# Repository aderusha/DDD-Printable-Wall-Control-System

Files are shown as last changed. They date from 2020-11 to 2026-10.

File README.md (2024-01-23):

# DDD Printable Wall Control System

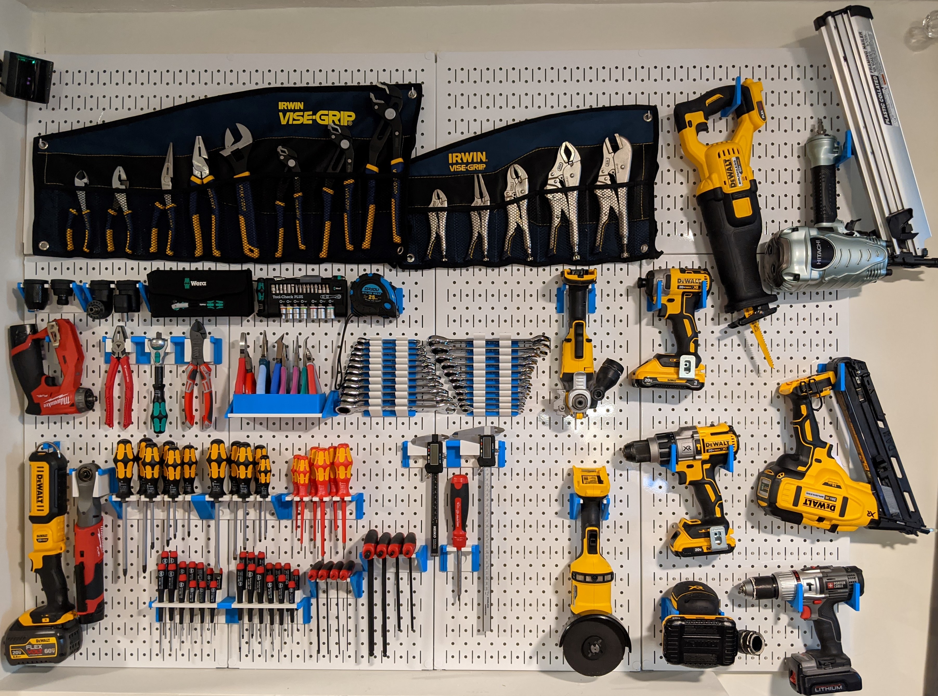
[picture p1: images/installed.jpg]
Installed DDD Printable Wall Control System


The DDD Printable Wall Control project provides a wide range of modular pegboard hangers for use with the [Wall Control powder-coated steel pegboard solutions available on Amazon](https://amzn.to/35emTsm).  After much research I landed on Wall Control as a durable, high-strength and low-price organization solution which works with existing 1/4" standard pegboard pegs.  The panels also add 1" slots which allows for greater strength and rigidity for compatible hangers.  I've found their panels to be inexpensive, well-made, and available in a range of colors and sizes.

Wall Control sells [a line of high quality hanger accessories compatible with these slots](https://amzn.to/35fkhuu) and I've found them to be reasonably priced and of good quality.  However, printed solutions can offer a highly-customized solutions made at home for your own organization needs and can do so quickly and inexpensively.  One might consider leveraging both solutions as needs arise.

---

## DDD Printable Wall Control Designs

The DDD Printable Wall Control collection is designed for easy printability, with all parts provided in a printable orientation and no supports should required.  The [Quickhooks](Quickhooks) series are fast-printing models for lightweight use cases.  [Sidepieces](Sidepieces) and [Centerpieces](Centerpieces) snap together to create strong, modular hanger solutions.

| [Quickhooks](Quickhooks) | |
| --- | --- |
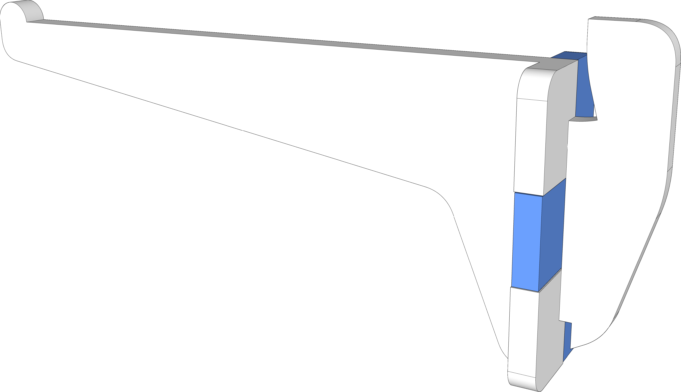
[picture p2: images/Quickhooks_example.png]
| [](Quickhooks) | [Quickhooks](Quickhooks) are fast-printing, two part hook/hanger solutions designed for quick and easy printing for lightweight use cases. Available in a range of sizes.|

| [Sidepieces](Sidepieces) | |
| --- | --- |
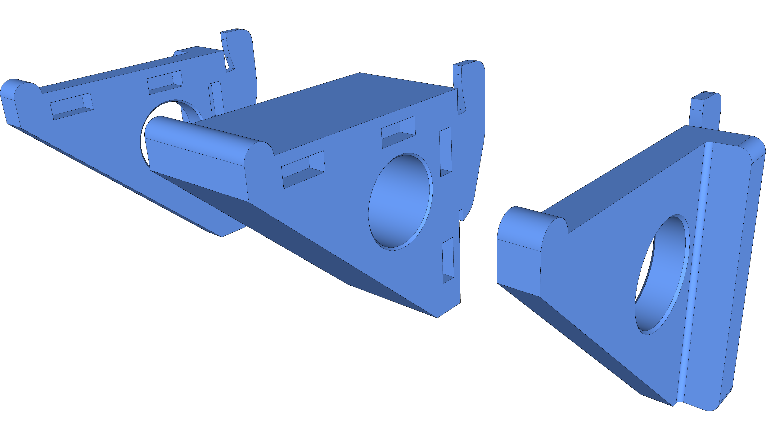
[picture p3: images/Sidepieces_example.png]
| [](Sidepieces) | [Sidepieces](Sidepieces) are designed with a hook that catches into the Wall Control slots.  Sidepieces extend out from the wall and come in a variety of lengths and shapes, and are offered in left/right/center variations.|

| [Centerpieces](Centerpieces) | |
| --- | --- |
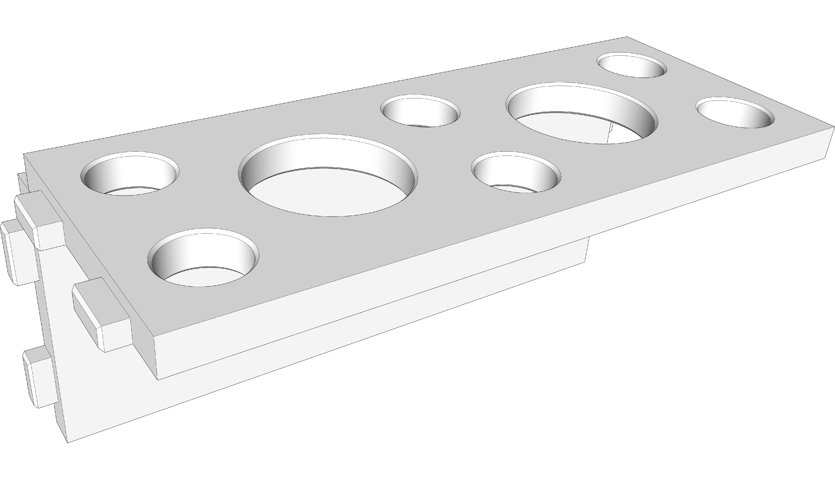
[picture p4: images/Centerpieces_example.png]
| [](Centerpieces) | [Centerpieces](Centerpieces) are designed to mount between a pair of sidepieces.  Centerpieces are designed to create custom hook, shelf, or hangar solutions which can snap into place between a variety of sidepieces. Some centerpiece models offer an additional locking feature which allows for completely rigid connections to a Wall Control panel.|

---

## Using DDD Printable Wall Control

The DDD system mixes "side pieces" with "center pieces"  to assemble a complete hanger.  Most use cases will involve a left/right combination of sidepieces with a centerpiece in the middle that will hold onto whatever you're hanging.

## Example DDD Printable Wall Control Recipe - belt clip hanger

Let's walk through an example hanger using DDD Printable Wall Control parts to create a hanger for tools with a belt clip such as a tape measure or pocket knife.  The completed model will look [something like this when empty](images/Recipies/belt-clip-hanger-empty.jpg) and [like this with some tools hung](images/Recipies/belt-clip-hanger-populated.jpg).

### Belt Clip Hanger printable BOM

Print the following parts for a 3in wide hanger as seen on the right in [the example photos above](images/Recipies/belt-clip-hanger-empty.jpg), substitute 4x wide or whatever you need for larger/smaller hangers.

* **1x [3x0 Flat Left.stl](Sidepieces/Flats/3x0%20Flat%20Left.stl)**  Left-hand sidepiece, 3 inches tall and flat in the front so there's nothing sticking forward. A sidepiece 3 high and 0 forward will have a filename starting with 3x0.
* **1x [3x0 Flat Right.stl](Sidepieces/Flats/3x0%20Flat%20Right.stl)**  Right hand sidepiece, same as above.
* **1x [2x3 Spacer clip-on.stl](Centerpieces/Spacer_clip-on/2x3%20Spacer%20clip-on.stl)**  Center hook for the clip, this one is 2in high and 3in across.  A centerpiece 2 high and 3 across will have a filename starting with 2x3.
* **1x [1x3 Locking Spacer.stl](Centerpieces/Locking_spacer/1x3%20Locking%20Spacer.stl)** Allows the hanger to be locked to the wall control panel via a locking pin.
* **1x [8mm Lock Pin.stl](Accessories/8mm%20Lock%20Pin.stl)**  Screws into the locking spacer to press a pin into the 1/4" holes on your Wall Control panel, providing a fully-constrained fit on the wall. Drive into place with a quarter-inch square drive ratchet. This is the core feature of this system, so print a bunch!
* **4x [4x10x8mm Pin.stl](Accessories/4x10x8mm%20Pin.stl)**  Some centerpieces do not have tabs on the model to press into the sidepiece, such as the "Spacer clip-on" centerpieces used in this recipe.  This is always a result of avoiding "supports" in the print job.  Print out a set of these 4 pins, press-fit on either side of the "Spacer clip-on" part, then press into the left/right sidepieces along with the Locking Spacer.

### To recap

* Sidepiece dimensions are `height x depth`
* Centerpiece dimensions are `height x width`
* Sidepieces come in left/right pairs.  They have a hook that connects to Wall Control and are usually used to attach a centerpiece to the wall
* Centerpieces usually are there to actually hold whatever you are trying to hang
* Locking spacers can be used to fully constrain the part so nothing moves around

### Geting Started tl;dr

Start with the centerpieces, find something suitable for the thing you want to hang, then find a matching set of sidepieces using the dimensions from the centerpiece.

# [More Recipes](https://github.com/aderusha/DDD-Printable-Wall-Control-System/wiki/Recipes)

[Check here](https://github.com/aderusha/DDD-Printable-Wall-Control-System/wiki/Recipes) for some parts lists ready-to-go to get an idea of how you can use this system, or add your own recipe to share your ideas with others!

# Other stuff

## Press-fit Tolerance

The parts are designed with a press-fit, one can use a vice or clamps to force the parts together.  The final fit will be determined by the calibration of your printer, if anything is loose you can add a drop of CA glue to keep parts held tightly.

## Locking Wall Control parts

Several [Centerpiece](Centerpieces) models offer a locking feature based on a fantastic idea from [Seth Altobelli](https://www.thingiverse.com/seth_a/designs).  A [locking screw](Centerpieces/Locking_spacer/8mm%20Lock%20Pin.stl) can be printed and screwed into these models to provide a solid, positive-lock fit with the Wall Control system.  A locked part is fully constrained and will not move while hanging or removing a tool which greatly improves the experience over traditional pegboard offerings.

The locking screw uses a 1/4" square drive, same as one would use to drive a 1/4" drive socket.

## About horizontal Wall Control Panels

Wall control sells panels which are oriented vertically or horizontally, and the hole patterns between the two are different. Centerpieces and sidepieces which make use of the locking feature have separate models for horizontal panels to accomodate the difference in hole patterns.

## About powder coated Wall Control Panels

Wall control panels are available in a range of colors or as a simple unpainted, steel sheet.  The slots cut in the plain steel panels are slightly wider than those in the powder coated panels due to the thickness of the paint itself.  The catches in these models are designed to attach firmly to the powder coated panels, while unpainted panels might have a little more play due to the difference in thickness.  If your assembled part doesn't fit tight, try including one of the locking parts to ensure a secure fit.

## Sources

While several-dozen variants of Quickhooks, Centerpieces and other models are available to download as `.stl` files; you can download and modify the following sources to customise various parts for your needs.

- *[SketchUp Sources](Sources/SketchUp)* - The original sources used to create the base models found in this repository. _Requires SketchUp 2021 or later, with [special instructions for exporting](https://github.com/aderusha/DDD-Printable-Wall-Control-System/issues/3#issuecomment-754100336)_.
- *[FreeCAD Sources](Sources/FreeCAD)* - Reverse-engineered parametric models maintained by [Flynn](https://github.com/f1yn). Includes source files for Quickhooks and Centerpieces, with more on the way. _Requires FreeCAD 0.20 or later, but can also be easily converted to `.step`_

## Join the discussion!

Click the [Discussions](https://github.com/aderusha/DDD-Printable-Wall-Control-System/discussions) link above to ask questions, get help, suggest new ideas, or submit your own models!

## [Buy me a coffee](https://www.buymeacoffee.com/gW5rPpsKR)

Buy me a coffee (https://www.buymeacoffee.com/gW5rPpsKR)

This project is powered by coffee.  [I might get a little weird about it at times](https://github.com/aderusha/RoastLearner), but it's not much of a stretch to suggest that coffee both powers and consumes a fair portion of my mental energy.  [Hook me up if you think these models are cool](https://www.buymeacoffee.com/gW5rPpsKR).  Thanks!

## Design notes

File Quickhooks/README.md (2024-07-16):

# DDD Printable Wall Control Quickhooks

Quickhooks are fast-printing, two part hook/hangar solutions designed for quick and easy printing for lightweight use cases. Quickhooks come in 3 variations based on strength (light/medium/heavy) and length (1/2/3").

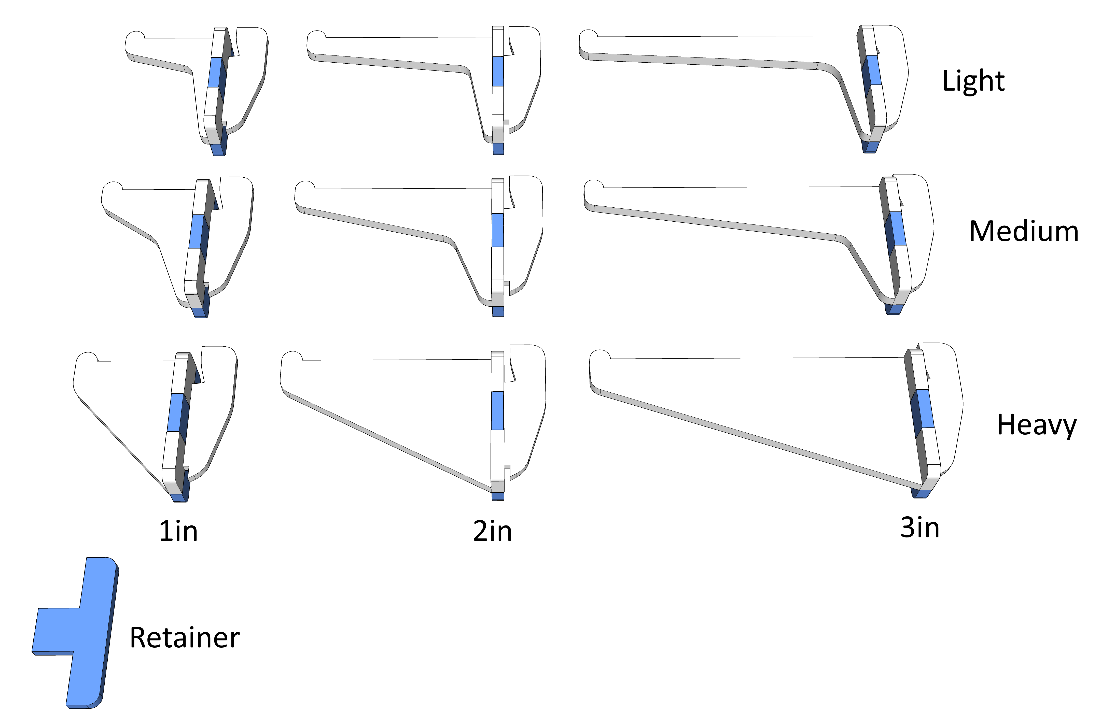
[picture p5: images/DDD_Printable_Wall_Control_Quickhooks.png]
Quickhooks


---

## Printing notes

Quickhooks should be suitable for fast printing, set your slicer up for maximum perimeters to ensure a strong printed result.  The retainer is press fit into the quickhook body. I use a clamp to apply a steady force to press the retainer into place. A rubber mallet is another good way to press fit together a quickhook and a retainer.

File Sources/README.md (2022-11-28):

# DDD Printable Wall Control System Source Designs

---

## Parametic templates in Fusion360 & STEP formats

These are for designing your own tool holders. 

| [Centerpiece Template](Fusion360/Parametric%20Centerpiece%20Template.f3d) | |
| --- | --- |
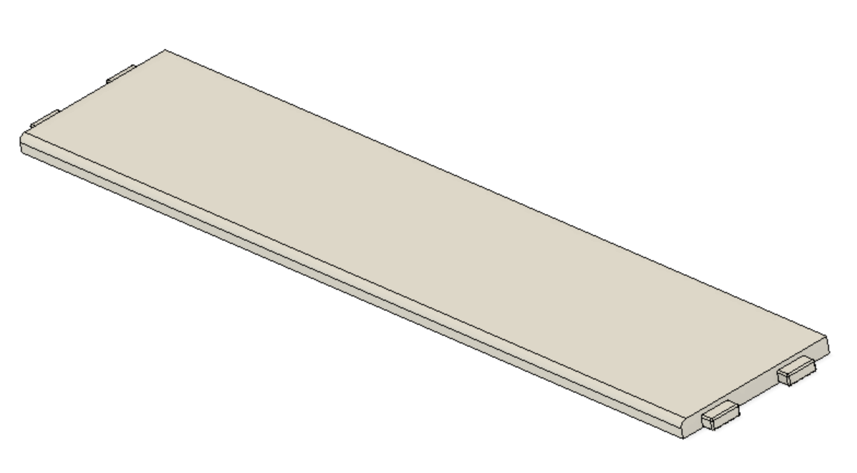
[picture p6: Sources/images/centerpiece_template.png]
| [](Fusion360/Parametric%20Centerpiece%20Template.f3d) | [Parametric Centerpiece Template](Fusion360/Parametric%20Centerpiece%20Template.f3d) is a simple centerpiece template for starting the design of your own tool holders. Specify parameters for the size and number of mounting tabs, then add your own sketches for custom fit holders. Also availabe in [STEP](Step/Parametric%20Centerpiece%20Template.f3d) format.|

| [Divider Rack Template](Fusion360/Parametric%20Centerpiece%20Divider%20Rack%20Template.f3d) | |
| --- | --- |
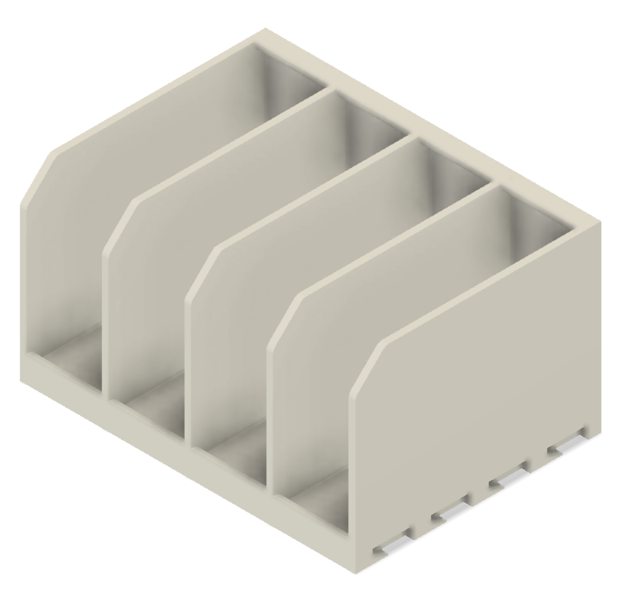
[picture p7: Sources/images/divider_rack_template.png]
| [](Fusion360/Parametric%20Centerpiece%20Divider%20Rack%20Template.f3d) | [Parametric Divider Rack Template](Fusion360/Parametric%20Centerpiece%20Divider%20Rack%20Template.f3d) is a simple centerpiece template for starting the design of storage for odd shaped items like pliers, brushes, phones, and more. Specify parameters for the size and number of mounting tabs, and the number of divded slots. Tall items (more than about 5 or 6cm) aren't able to be attached to [sidepieces](../Sidepieces/] first, and then attached to the wall control panel. They won't be able to lean back far enough for the mounting tabs to slot into the panel. So this template creates slots instead of tabs for the divider rack. Use the [4mmx10mmx8mm](../Accessories/4x10x8mm%20Pin.stl) pin provided in the [Accessories](../Accessories/), and press it into the sidepiece you choose. Then mount the sidepieces on the panel first, and you'll be able to attach the divider rack between them by lowering it onto the sidepiece tabs, and sliding it backwards to lock into place. The tolerances here are pretty generous so even if your printer isn't perfectly tuned, it should still fit. Also availabe in [STEP](Step/Parametric%20Centerpiece%20Divider%20Rack%20Template.step) format.|

---

## Using Parametric Source Files
These source files aren't directly printable and will need to be modified to suit your needs with some CAD tool that can use (or convert) F360 or Step formats. They use metric measurments. 

Save the template as a new file (to preserve the original template) and then modify as needed. You can specify the width (in "Units" on the Wall Control Board), Depth, and Height as well as the number of mounting tabs to use for attaching to [sidepieces](../Sidepieces/]. Then you can add your own sketches and extrusions to make holders for your own tools, and export that as a mesh to your slicer for printing. 

A "Width Unit" here is the meaurement between mounting slots, minus the mounting tabs. Vertical wall control panels have 14 units of width, and horizontal panels have 31. 

Available User Parameters

CenterPieceWidthUnits: Number of spaces on the wall control pegboard.  Minimum 1,  maximum 14 for vertical wall control panels and 31 for horizonal panels.  Realistically your printer dimensions will determin how big you can make this.

CenterPieceDepth: Depth measurement from the wall control board extending out into space.  Minimum 17mm to fit at least one mounting tab.  Maximum  ¯\\_(ツ)_/¯
CenterPieceThickness: Lower measurements make for good shelf-like objects,  taller measurement make for better custom tool holders.  Minimum 5mm to ensure there's enough space for mounting tabs. Maximum  ¯\\_(ツ)_/¯

CountMountingTabs: Specify the number of mounting tabs to attach a sidepiece

DividerWallThickness: Specify the thickness of the divider walls (including the outter side and back walls)

DividerWallHeight: Specify how tall the divider walls should be (including the outter side and back walls)

DividerSlots: Specify the number of tool storage slots.  Minimum 1 for a single compartment (one divider wall is always combined inside of a side wall).  Maximum  ¯\\_(ツ)_/¯

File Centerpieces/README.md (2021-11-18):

# DDD Printable Wall Control Centerpieces

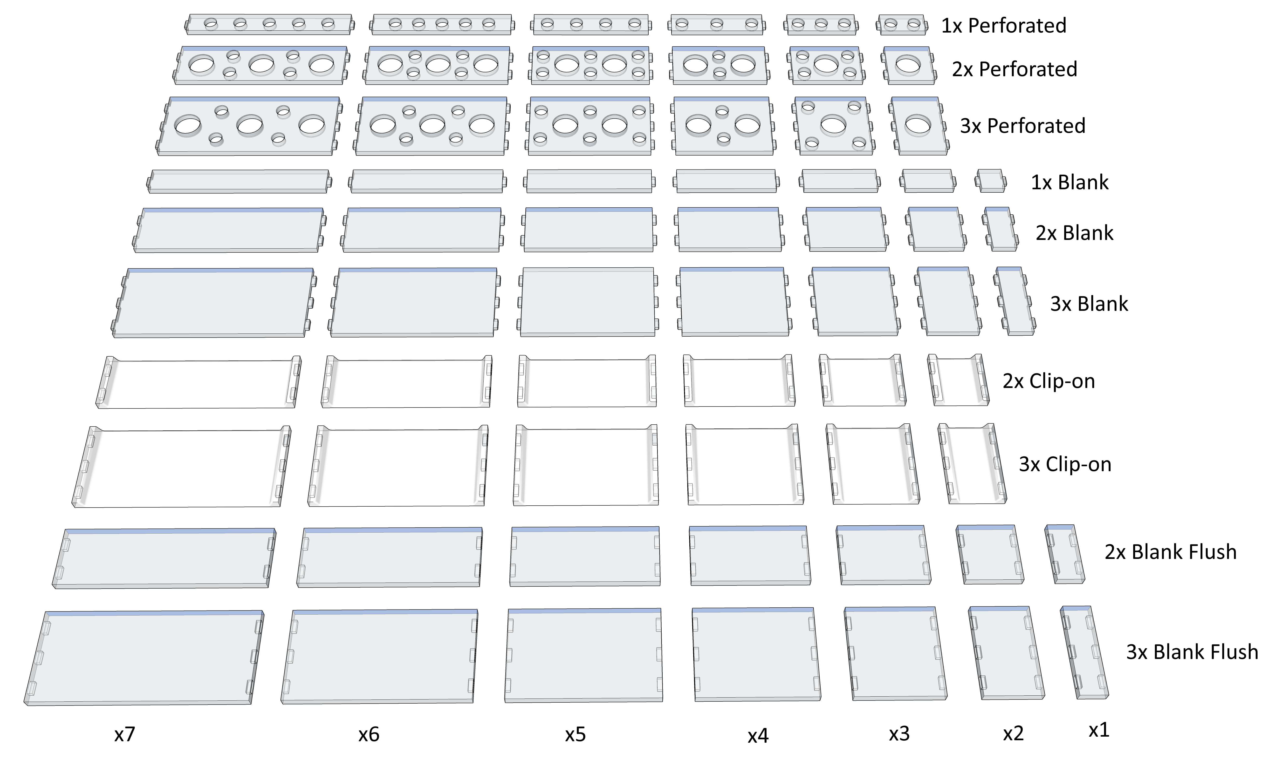
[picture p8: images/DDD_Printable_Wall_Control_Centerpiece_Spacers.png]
Centerpiece Spacers


Centerpieces mount between sidepieces to create a custom hanging solution by combining snap-fit modular components.

## Centerpiece Naming

Centerpiece names start with the dimensions, roughly equivalent to inches as used on the Wall Control system.  A 2x4 Centerpiece is 2in in height and fits between sidepieces that are 4in apart.

---

## Centerpiece Models

### [Tool_hooks](Tool_hooks/)

Centerpiece models designed for specific tools and applications.

### [Locking Spacer](Locking_spacer/)

Spacers with threads for the [8mm Lock Pin](Locking_spacer/8mm%20Lock%20Pin.stl) which will lock the assembled hanger to the Wall Control board.  Use these as vertical spacers between your sidepieces to create a solid mounting solution for nearly anything.

### [Locking Spacer for Horizontal Wall Control](Locking_spacer_for_horizontal_Wall_Control/)

Same as above, but for Horizontal Wall Control panels which have a different hole pattern.

### [Spacer Blank](Spacer_blank/)

Simple, blank models with connection pins on either side in various sizes.  Great choice for horizontal use as a shelf.

### [Spacer Blank Flush](Spacer_blank_flush/)

These spacers mount flush to both the back and front of the side pieces, which requires the use of 4 or 6 [4x10x8mm Pins](4x10x8mm Pin.stl) along the edges to connect them to a sidepiece. Another good choice for horizontal use as a shelf, I've also used these parts mounted vertically to provide a large flat surface for attaching adhesive-backed Velcro strips.

### [Clip-on Spacer](Spacer_clip-on/)

Another flush-mount design requiring 4 or 6 [4x10x8mm Pins](../Accessories/4x10x8mm%20Pin.stl) for mounting between side pieces.  The clip-on spacer provides a vertical surface set a few mm away from the wall panel so that one can mount clip-on parts such as a tape measure.

### [U hooks](U_hooks/)

U hooks useful for mounting horizontally between side pieces to hang tools.

### [Spacer Perforated](Spacer_perforated/)

Models with 1/2" and 1" holes along the flat surface for additional rigidity, interesting aesthetics, or to hold things with 1/2" or 1" round features.

---

## Printing notes

In most use cases, the centerpieces are loaded with a bending moment, which is only really a problem when using the longer (4"+) models.  Adding infill and perimeters can help with rigidity, but for most cases simply printing fast and cheap should work fine.  PLA is a good choice for maximum rigidity.

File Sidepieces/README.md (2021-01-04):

# DDD Printable Wall Control Sidepieces

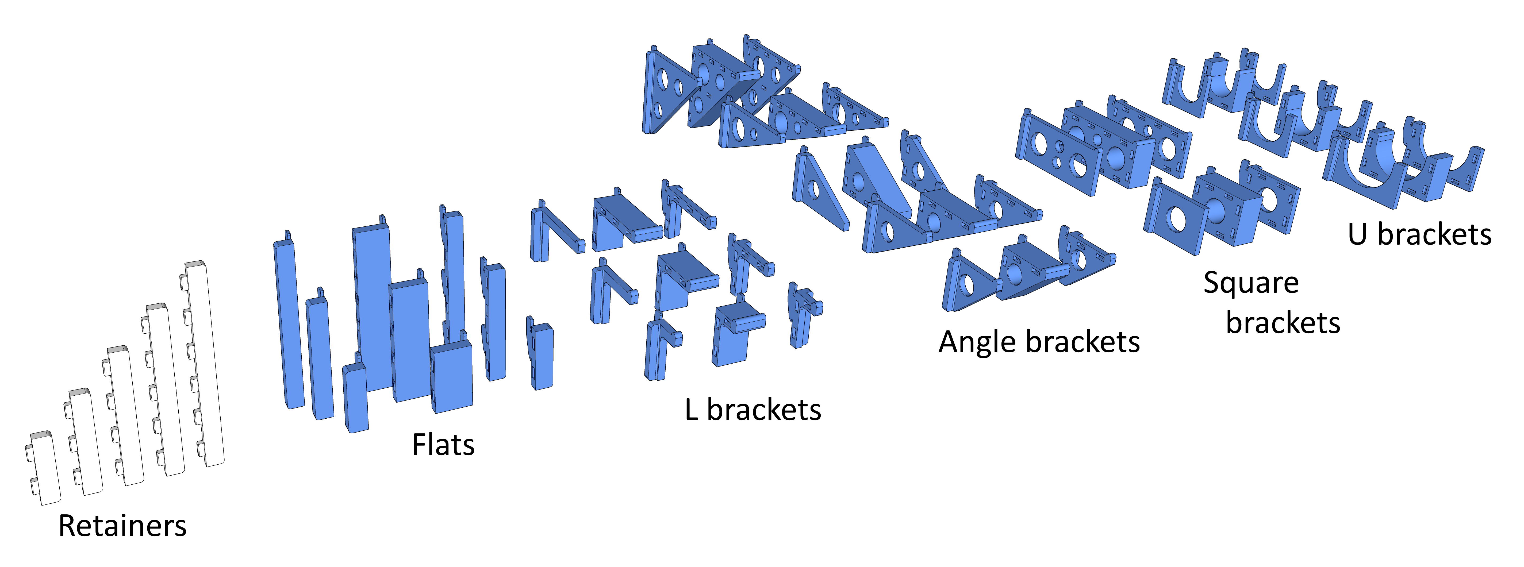
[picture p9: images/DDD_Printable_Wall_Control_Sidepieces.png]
Sidepieces


Sidepieces are used to connect to the Wall Control through the 1in slots and extend forward out from the wall.  Sidepieces can work on their own with a retainer which can be useful to create a single hook.  Alternately, sidepieces can be hooked together via centerpieces to create a wide range of modular hanging solutions.

## Sidepiece Naming

Sidepiece names start with the dimensions, roughly equivalent to inches as used on the Wall Control system.  For example, a 2x4 Sidepiece is 2in in height and extends 4in out from the base (which itself is 8.8mm in front of the wall panel).

---

## Sidepiece Models

### [Retainers](Retainers/)

Retainers are used when a sidepiece is used without one or more centerpieces, providing a secure fit against the Wall Control board.  Standard retainer models are narrow enough to allow side-by-side placement with an adjacent sidepiece + retainer.  Locking retainers are wider but can be used with the [8mm lock pin](Retainers/8mm%20Lock%20Pin.stl) to lock the hanger to the panel. Models are provided in 2/3/4/5/6 inch heights.

### [Flats](Flats/)

Simple, flat-surface sidepieces allowing centerpieces to be mounted vertically against the Wall Control board.  Useful with flush-mounted Centerpieces.

### [L Brackets](L_brackets)

"L" shaped brackets, good for lightweight loads or for use as hooks.  Models are available with a flat top, or with a 1/4" round "hook" feature which can help to retain parts hung on these models.

### [Angle Brackets](Angle_brackets)

Angle brackets good for holding moderate loads, general-purpose solution for mounting centerpieces horizontally.  Available in "flat" or "hook" variations.

### [Square Brackets](Square_brackets/)

Square brackets good for holding heavy loads.  With a full complement of centerpieces mounted between two square brackets, one can create a "torsion box" which can be helpful for mounting things which might be hanging off to one side of the hanger, presenting a twisting force on the bracket.  Available in "flat" or "hook" variations.

### [U Brackets](U_brackets/.)

U brackets are useful as "hooks" for mounting nearly anything.  Use with a [retainer](Retainers/) to create a single hook which is useful for hanging power tools, or combine a left/right pair of U brackets to hang a drill.

### [Dowel Rod Hangers](Dowel_rod_hanger/.)

Hangers to hold dowel rods, allowing one to mount things with a transverse hole such as spools.

---

## Printing notes

The sidepieces bear most of the load for an assembled hanger solution.  The downward forces press up against a catch on the bottom of the slot hook on each sidepiece, while the outward and rotational forces pull against the top-most portion of that same catch.  I've found printing with 100% perimeters in the catch area provides the strongest print. PLA is a good choice for maximum rigidity.

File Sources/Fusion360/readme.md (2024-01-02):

# Vertical Locking Spacers

[Note - submitted by @Akasnajo.  Thanks man!]

To create larger spacer panels:

To make taller, combine same-length panels as necessary... simply put the top/bottom faces together and combine into one body.

To make longer, identify two same-height panels that combine to yield the desired length.
Ignore (or delete) the tabs of the sides to be joined.
Place the two joining faces 2.4mm apart and extrude until they are joined.

If this is confusing, practice by combining two 1x2 pieces into a 2x2 panel and then combine two 2x1 panels into a 2x2 panel.
Compare to provided 2x2 panels to understand where adjustments must be made.

Thanks to those whose work this Fusion 360 version was created upon.

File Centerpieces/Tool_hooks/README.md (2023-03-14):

# DDD Printable Wall Control Centerpiece Tool Hooks

Centerpiece tool hooks designed for specific tool applications.

## Centerpiece Tool Hooks Naming

Centerpiece names start with the dimensions, roughly equivalent to inches as used on the Wall Control system.  A 2x4 Centerpiece is 2in in height and fits between sidepieces that are 4in apart.

---

## Centerpiece Tool Hooks

* ### 3x7 Benchtop Hand Tool [Tray](3x7%20Benchtop%20Hand%20Tool%20Holder%20Tray.stl) and [Holder](3x7%20Benchtop%20Hand%20Tool%20Holder.stl)

  Removable tray to hold 8 small hand tools like pliers or cutters.  Set your most commonly-used hand tools in the tray to give you an easy-to-grab solution to bring to your bench with all your tools in easy reach near the work.

* ### [11pc Wrench Hangers](1x6%2011pc%20Wrench%20Hanger.stl)

  Holds an 11 piece set of SAE box-end wrenches, combine with the [Inverted model](1x6%2011pc%20Wrench%20Hanger%20Inverted.stl) to hold a [22 piece set like this](https://amzn.to/35fa7dd).  Print with a left/right/center set of [6x0 Flats](../../Sidepieces/Flats) and at least 8x [4x10x8mm Pins](../Spacer_blank_flush/4x10x8mm%20Pin.stl).

* ### [2x4 10x](2x4%2010x%2010mm%20Screwdriver%20Holder.stl) and [2x5 13x 10mm Screwdriver Holder](2x5%2013x%2010mm%20Screwdriver%20Holder.stl)

  Holds 10x or 13x 10mm-wide screwdrivers (or similar).  I like [Wiha precision tools](https://amzn.to/2GQ8ucA) and these were designed to fit.  Combine with [2x2 L Brackets](../../Sidepieces/L_brackets/) and a [2x5 spacer](../../Centerpieces/Spacer_perforated/2x5%20Spacer%20perforated.stl).

* ### Chinese Digital Calipers [150mm](1x3%20Chinese%20Digital%20Calipers%20150mm.stl) and [300mm](1x3%20Chinese%20Digital%20Calipers%20300mm.stl)

  Designed for [150mm](https://amzn.to/3pcWByG) and [300mm](https://amzn.to/2UdfQdb) calipers of the sort you'll find from various Chinese vendors.  Combine with [2x1 L Brackets](../../Sidepieces/L_brackets/), a [2x3 locking spacer](../../Centerpieces/Locking_spacer/2x3%20Locking%20Spacer.stl), 4x [4x10x8mm Pins](../Spacer_blank_flush/4x10x8mm%20Pin.stl), and an [8mm Lock Pin](../../Centerpieces/Locking_spacer/8mm%20Lock%20Pin.stl) to keep it in place.

* ### Milwaukee M12 Battery holder for [one](2x2_milwaukee_M12_battery_x1.stl), [two](2x5_milwaukee_M12_battery_x2.stl), or [three](2x8_milwaukee_M12_battery_x3.stl) batteries

  Holders for M12 Milwaukee batteries. Each one requires [2x0 Flat Left](../../Sidepieces/Flats/2x0%20Flat%20Left.stl) and [2x0 Flat Right](../../Sidepieces/Flats/2x0%20Flat%20Right.stl) sidepieces along with 4 of the [4x10x8mm pins](../../Accessories/4x10x8mm%20Pin.stl). Photos available in my [Printables page](https://www.printables.com/model/352898-milwaukee-m12-battery-holder-for-wall-control-pegb). These were remixed from [Yangorang's design](https://www.printables.com/model/75300-power-tool-battery-wall-control-pegboard-mounts-fo) which requires nuts and bolts - whereas the version here is fully printable.
  
* ### Milwaukee M12 Generic Tool holders
  These are tool holders that should work for almost all Milwaukee M12 tools, although you should mind how heavy the tools are. There are several variations for holding the tools sideways and flat agains the pegboard (better for heavier tools) and angled ones where the tool points away from the wall:
    * [Straight](2x1_Milwaukee_M12_tool_holder_straight.stl): tool is held vertically and parallel to the wall, likelly better for some heavier tools since it won't stress the sidepiece hooks as much.
    * [Straight Extended](2x1_Milwaukee_M12_tool_holder_straight_extended.stl): Same as straight, but arm juts out further from pegboard for wider tools.
    * [Angled](2x1_Milwaukee_M12_tool_holder_angled.stl): 
  Each one requires [2x0 Flat Left](../../Sidepieces/Flats/2x0%20Flat%20Left.stl) and [2x0 Flat Right](../../Sidepieces/Flats/2x0%20Flat%20Right.stl) sidepieces along with 4 of the [4x10x8mm pins](../../Accessories/4x10x8mm%20Pin.stl). Photos available in my [Printables page](https://www.printables.com/model/352915-milwaukee-m12-tool-holders-for-wall-control-pegboa). These were remixed from [Yangorang's design](https://www.printables.com/model/75300-power-tool-battery-wall-control-pegboard-mounts-fo) which requires nuts and bolts - whereas the version here is fully printable. It also has added reinforcement on the arms.
  
  * ### [2.25x2 Milwaukee 3/8" Cordless Ratchet](2x2%20Milwaukee%203-8%20Cordless%20Ratchet.stl)

  Tool holder for the [Milwaukee 3/8" M12 Fuel Cordless Ratchet](https://amzn.to/2IsC9ZB).  Combine with a pair of [2x2 L Brackets](../../Sidepieces/L_brackets/).

* ### Wiha 33496 8-Piece T-Handle Hex Drivers ([M10/8/6/5](1x3%20Wiha%20T-Handle%20M10%20M8%20M6%20M5.stl) and [M4/3/2.5/2](1x4%20Wiha%20T-Handle%20M4%20M3%20M2.5%20M2.stl))

  Holders for the [Wiha 33496 8-Piece T-Handle Hex Driver set](https://amzn.to/36gpuRK), split into two parts.  The [larger set](1x3%20Wiha%20T-Handle%20M10%20M8%20M6%20M5.stl) needs to be set 3" away from the panel for the T-Handles to fit, so pair with [2x3 Angle Brackets](../../Sidepieces/Angle_brackets/) and a [2x4 spacer](../../Centerpieces/Spacer_perforated/2x4%20Spacer%20perforated.stl).  The [smaller set](1x4%20Wiha%20T-Handle%20M4%20M3%20M2.5%20M2.stl) can set closer to the wall if desired, using [2x2 Angle Brackets](../../Sidepieces/Angle_brackets/) and a [2x3 spacer](../../Centerpieces/Spacer_perforated/2x3%20Spacer%20perforated.stl).

* ### Wera 5023451001 10-Piece Imperial T-Handle Hex Plus Drivers ([Large drivers](2x5%20Wera%20HexPlus%20T-Handle%20Imperial%20Large.stl) and [Small drivers](2x4%20Wera%20HexPlus%20T-Handle%20Imperial%20Small.stl))

  Holders for the [Wera 5023451001 10-Piece Imperial T-Handle Hex Plus Drivers](https://amzn.to/3ggLkL6), split into two parts.  Pair with [2x2 Angle Brackets](../../Sidepieces/Angle_brackets/) and a [2x5 spacer](../../Centerpieces/Spacer_perforated/2x5%20Spacer%20perforated.stl) for the larger 5 drivers, and a [2x4 spacer](../../Centerpieces/Spacer_perforated/2x5%20Spacer%20perforated.stl) for the smaller 5 drivers

* ### [Wera 5023450001 7-Piece Metric T-Handle Hex Plus Drivers](2x6%20Wera%20HexPlus%20T-Handle%20Metric.stl)

  Holders for the [Wera 5023450001 7-Piece Metric T-Handle Hex Plus Drivers](https://amzn.to/3vfSXGa).  Pair with [2x3 Angle Brackets](../../Sidepieces/Angle_brackets/) and a [2x6 spacer](../../Centerpieces/Spacer_perforated/2x6%20Spacer%20perforated.stl)

* ### [Wera 5003550001 Zyklop 3/8" Ratchet](1x2%20Wera%203-8%20Zyklop%20Ratchet.stl)

  Fits the [Wera 5003550001 Zyklop 3/8" Ratchet](https://amzn.to/35fuVRI).  Combine with [1x2 L Brackets](../../Sidepieces/L_brackets/) and a [2x2 spacer](../../Centerpieces/Spacer_perforated/2x2%20Spacer%20perforated.stl).

* ### [Wera Kraftform Plus 160i/6 Insulated Screwdrivers](2x5%20Wera%20Kraftform%20Plus%20160i-6.stl)

  Fits the [Wera Kraftform Plus 160i/6 Insulated Screwdriver set](https://amzn.to/36il4tO).  Print with [2x2 Angle Brackets](../../Sidepieces/Angle_brackets/) and a [2x5 spacer](../../Centerpieces/Spacer_perforated/2x5%20Spacer%20perforated.stl).

* ### [Wera Kraftform 917+918 Chiseldrivers](2x6%20Wera%20917+918.stl)

  Holds a set of [6 drivers from the Wera 917 and 916 Chiseldrivers](https://amzn.to/35iAoXX) (1/2/3 Phillips and Pozidriv).  Print with [2x2 Angle Brackets](../../Sidepieces/Angle_brackets/) and a [2x6 spacer](../../Centerpieces/Spacer_perforated/2x5%20Spacer%20perforated.stl).  The 6" span on this needs some strength, I recommend printing this one with 100% perimeters.  It'll take a while to print but the result will be plenty rigid.

* ### [Wera Kraftform 923 slotted Chiseldrivers](2x5%20Wera%20932.stl)

  Holds a set of [5 Wera 932 slotted Chiseldrivers](https://amzn.to/35iAoXX).  Print with [2x2 Angle Brackets](../../Sidepieces/Angle_brackets/) and a [2x5 spacer](../../Centerpieces/Spacer_perforated/2x5%20Spacer%20perforated.stl).

* ### [NWS 138-69-200 Fantastico Plus Side Cutters](1x2%20NWS%20138-69-200%20Fantastico%20Plus%20Side%20Cutters.stl)

  Holds the fantastic [NWS 138-69-200 Fantastico Plus Side Cutters](https://amzn.to/3eNrbKv).  Combine with [1x2 L Brackets](../../Sidepieces/L_brackets/) and a [2x2 spacer](../../Centerpieces/Spacer_perforated/2x2%20Spacer%20perforated.stl).

* ### [Vampliers VT-001-8](1x2%20Vampliers%20VT-001-8.stl)

  Hanger for the best damn lineman's pliers ever made - the [Vampliers VT-001-8](https://amzn.to/3khDUpO).  Pair with [1x2 L Brackets](../../Sidepieces/L_brackets/) and a [2x2 spacer](../../Centerpieces/Spacer_perforated/2x2%20Spacer%20perforated.stl).

* ### [DeWalt DCB118 Charger](2x7%20DeWalt%20DCB118%20Charger.stl)

  Mount for the [DeWalt DCB118 20v/60v quick charger](https://amzn.to/36yhLio) with locking feature.  This is DeWalt's fastest charger yet, works with all modern 20v and 60v batteries.  Combine with [2x0 Flat Brackets](../../Sidepieces/Flats/), 4x [4x10x8mm Pins](../Spacer_blank_flush/4x10x8mm%20Pin.stl), and two [8mm Lock Pins](../../Centerpieces/Locking_spacer/8mm%20Lock%20Pin.stl) to keep it in place.

* ### [DeWalt DCB095 Charger](3x1%20DeWalt%20DCB095%20Charger.stl)

  Mount for the [DeWalt DCB095 8v charger](https://amzn.to/3fpajda) with locking feature.  Charger for the 8v battery system used by their [powered screwdrivers](https://amzn.to/3fpajda).  Print left/right [3x0 Flat Brackets](../../Sidepieces/Flats/), 4x [4x10x8mm Pins](../Spacer_blank_flush/4x10x8mm%20Pin.stl), and an [8mm Lock Pin](../../Centerpieces/Locking_spacer/8mm%20Lock%20Pin.stl) to keep it in place.

* ### [Milwaukee M12 Charger](4x3%20Milwaukee%20M12%20Charger.stl)

  Mount for the [Milwaukee M12 Charger](https://amzn.to/375AkL7) with locking feature, used for all M12 tools from Milwaukee.  Combine with [2x0 Flat Brackets](../../Sidepieces/Flats/), 4x [4x10x8mm Pins](../Spacer_blank_flush/4x10x8mm%20Pin.stl), and two [8mm Lock Pins](../../Centerpieces/Locking_spacer/8mm%20Lock%20Pin.stl) to keep it in place.

* ### [Milwaukee M12 FUEL Installation Drill/Driver](3x2%20Milwaukee%20M12%20Installation%20Drill.stl)

  Mount for the [Milwaukee M12 FUEL Installation Drill/Driver](https://amzn.to/3KmtOTe). Combine with Left/Right [3x0 Flat Brackets](../../Sidepieces/Flats/) to keep it in place. The [lock piece](3x2%20Milwaukee%20M12%20Installation%20Drill%20Lock.stl) is definitely optional. I thought I'd need it to keep it in place but it actually stays on the holder just fine without the lock piece.

* ### [28mm](2x2%2028mm%20Hammer%20Head%20Catch.stl) and [33mm Hammer Head Catch](2x2%2033mm%20Hammer%20Head%20Catch.stl)

  Mounts for claw/rip hammers, the 33mm was designed for the [Estwing Ultra Series 15oz E15SM](https://amzn.to/3puEnJa).  Pair with [2x2 L Brackets](../../Sidepieces/L_brackets/) and 4x [4x10x8mm Pins](../Spacer_blank_flush/4x10x8mm%20Pin.stl).

* ### [Porter Cable PCXMVC Charger](5x1%20Porter%20Cable%20PCXMVC%20Charger.stl)

  Mount for the Porter Cable PCXMVC Charger with locking feature, used for all 20V tools from Porter Cable.  Combine with left/right [5x0 Flat Brackets](../../Sidepieces/Flats/), 6x [4x10x8mm Pins](../Spacer_blank_flush/4x10x8mm%20Pin.stl), and two [8mm Lock Pins](../../Centerpieces/Locking_spacer/8mm%20Lock%20Pin.stl) to keep it in place.

---

## Printing notes

In most use cases, the centerpieces are loaded with a bending moment, which is only really a problem when using the longer (4"+) models.  Adding perimeters and infill can help with rigidity, but for most cases simply printing fast and cheap should work fine.  PLA is a good choice for maximum rigidity.

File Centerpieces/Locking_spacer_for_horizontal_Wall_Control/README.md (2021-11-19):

# DDD Printable Wall Control Locking Spacers for Horizontal Wall Control

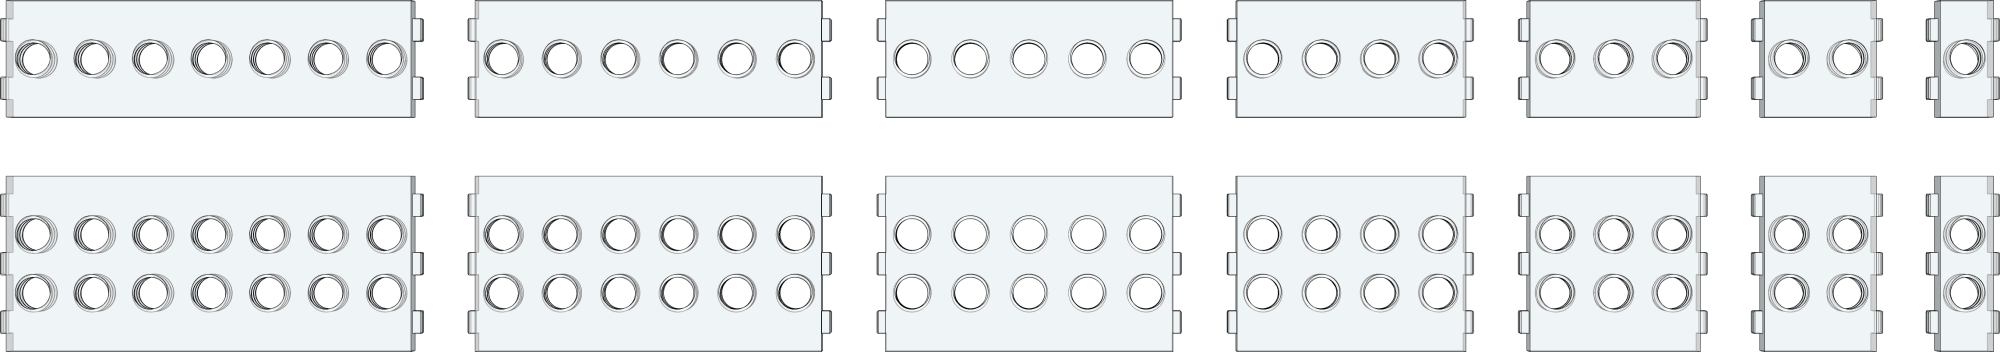
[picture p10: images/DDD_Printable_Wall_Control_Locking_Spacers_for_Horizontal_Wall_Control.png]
Locking Spacers


The locking spacer models provide an array of threaded holes which align with the 1/4" pegboard holes on a horizontal Wall Control panel.  Once mounted to the panel, you can screw in a [positive-lock pin](./8mm%20Lock%20Pin.stl) which securely anchors the model to a wall control panel in all 3 axis.  The pin has a cutout for a 1/4" square drive to screw it into the spacer.

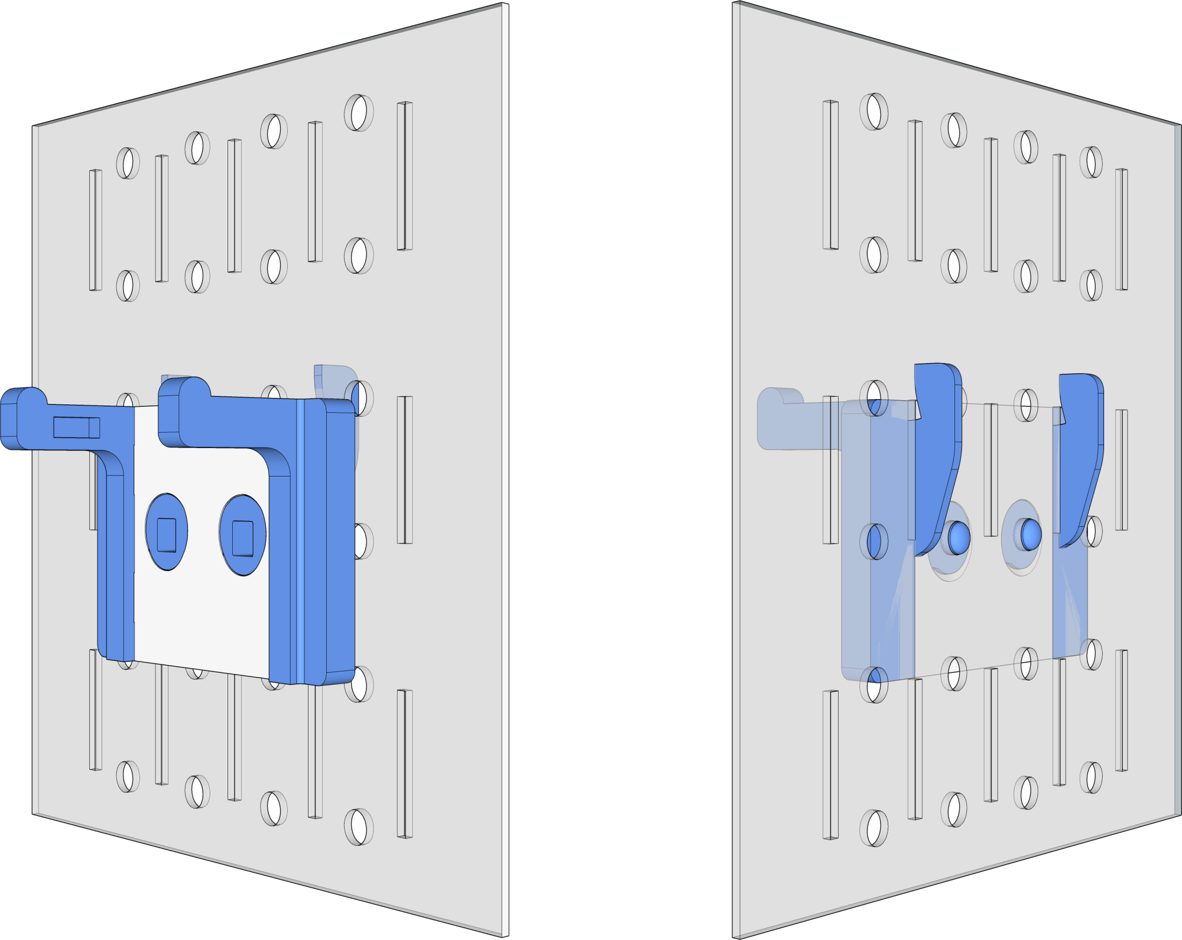
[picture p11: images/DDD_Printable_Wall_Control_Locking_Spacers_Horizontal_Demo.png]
Locking Spacer Demo


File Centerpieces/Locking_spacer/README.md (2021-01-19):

# DDD Printable Wall Control Locking Spacers

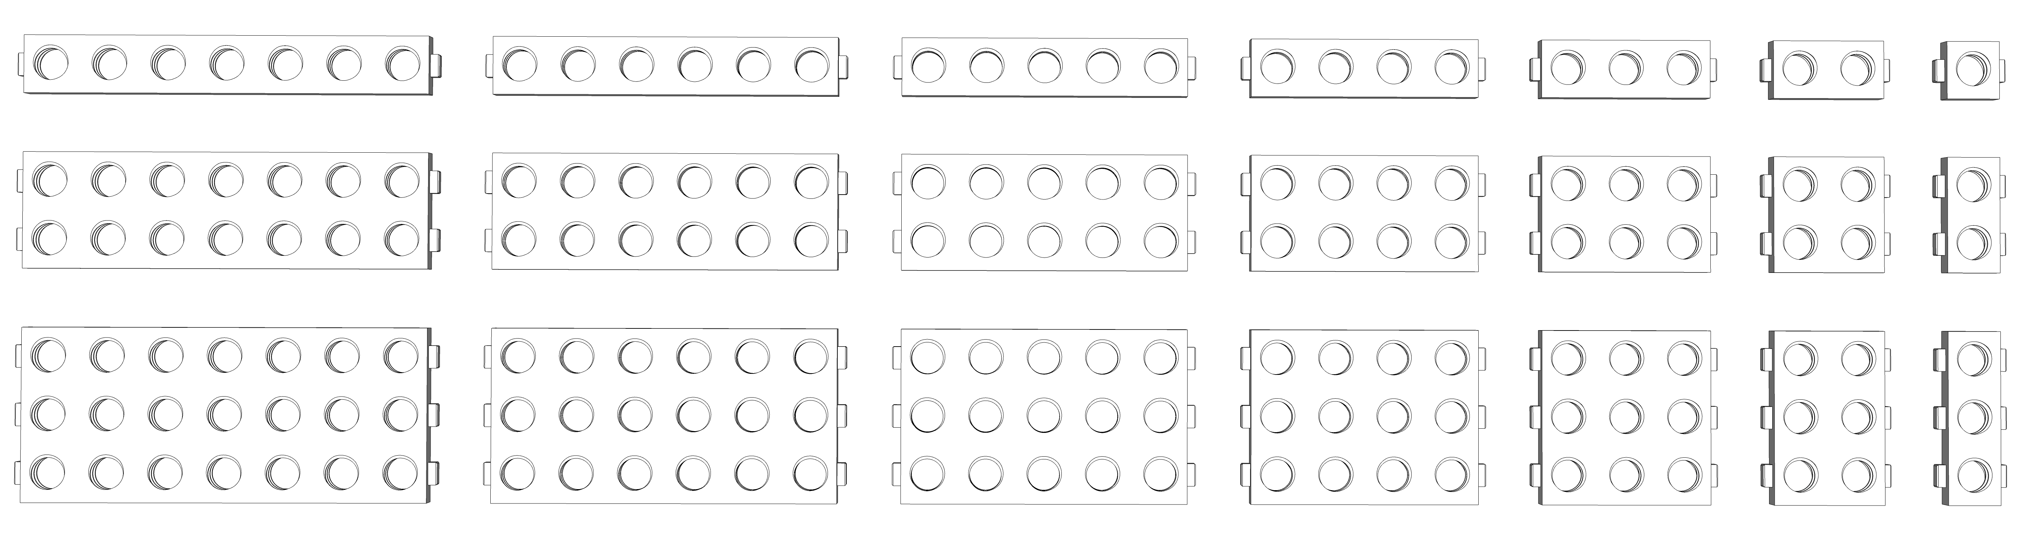
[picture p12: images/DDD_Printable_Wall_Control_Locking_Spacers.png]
Locking Spacers


The locking spacer models provide an array of threaded holes which align with the 1/4" pegboard holes on a Wall Control panel.  Once mounted to the panel, you can screw in a [positive-lock pin](./8mm%20Lock%20Pin.stl) which securely anchors the model to a wall control panel in all 3 axis.  The pin has a cutout for a 1/4" square drive to screw it into the spacer.

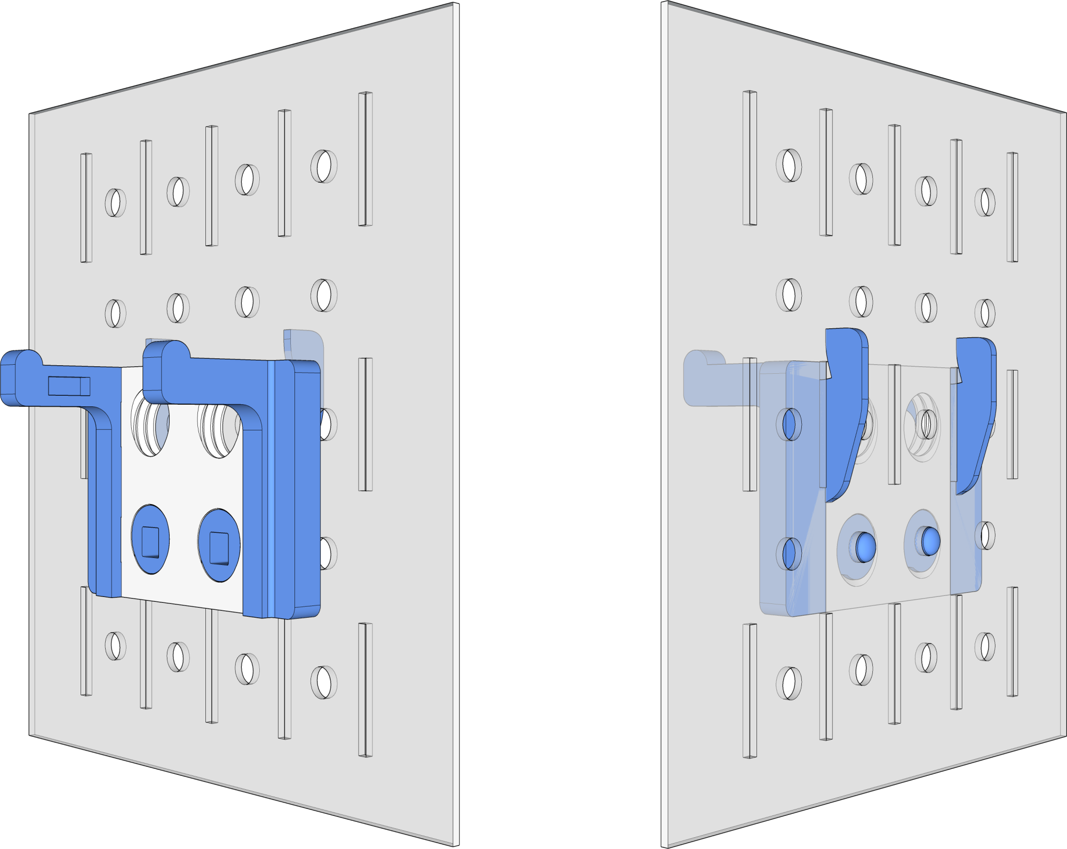
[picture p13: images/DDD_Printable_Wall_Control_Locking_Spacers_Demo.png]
Locking Spacer Demo


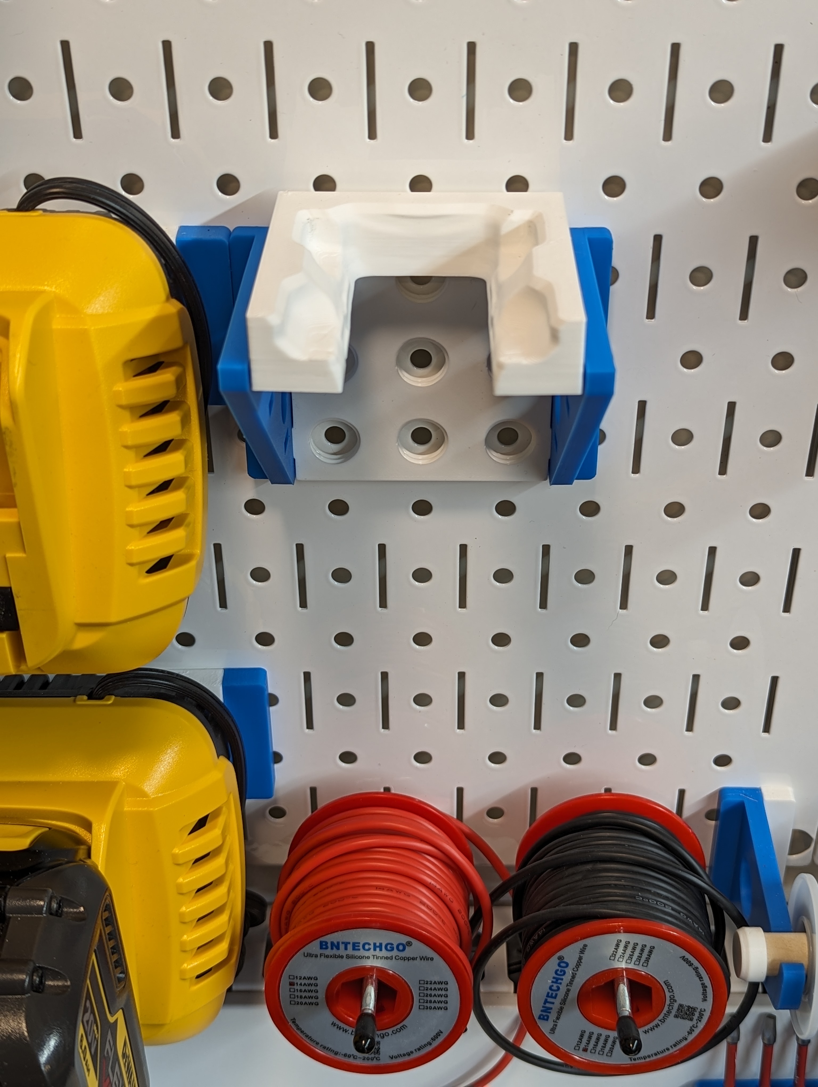
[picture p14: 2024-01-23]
images/Recipies/DeWalt-DCF923-empty.jpg

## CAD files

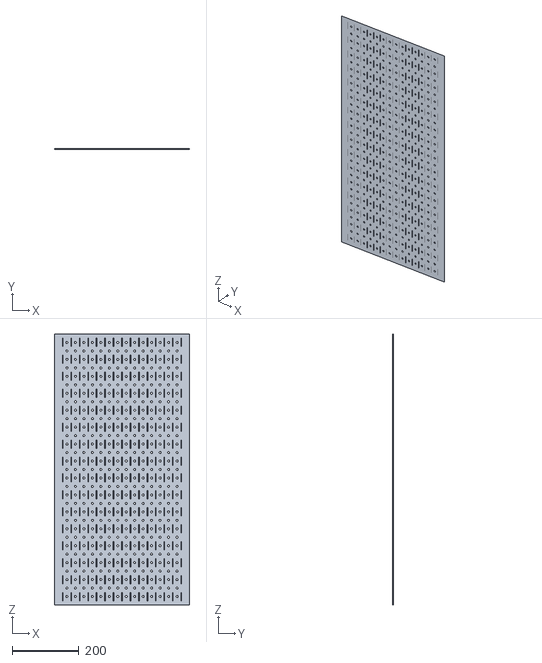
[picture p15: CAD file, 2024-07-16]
Accessories/Wall Control Panel Model.stl
406.4 x 1.59 x 812.8

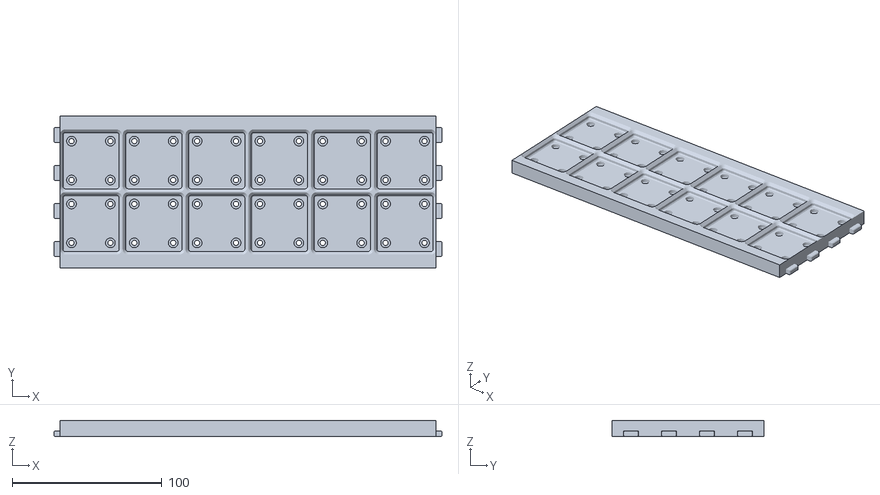
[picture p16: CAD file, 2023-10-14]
Centerpieces/Gridfinity/4x10 Gridfinity Frame 2x6.stl
259.4 x 101.4 x 10.8

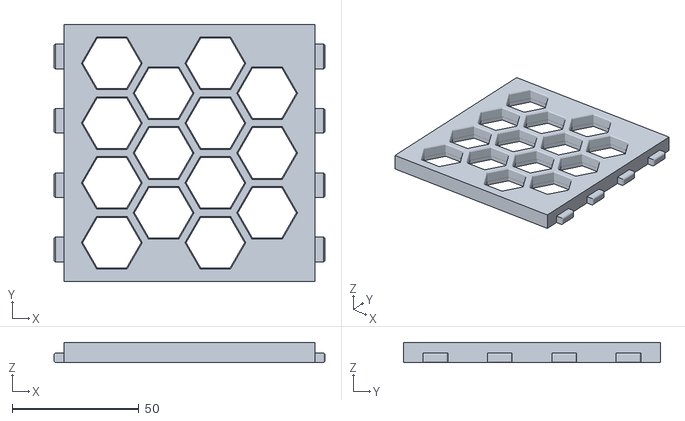
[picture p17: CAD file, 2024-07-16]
Centerpieces/Honeycomb_Storage_Wall/4x4 Honeycomb Storage Wall.stl
107.0 x 101.4 x 8.00

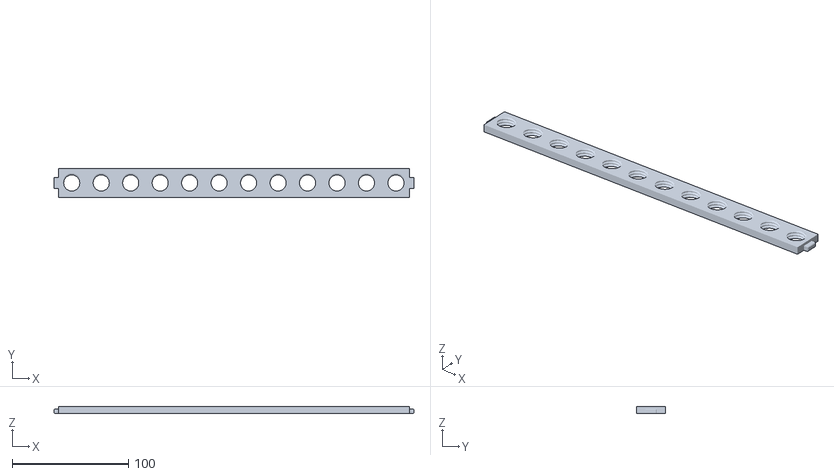
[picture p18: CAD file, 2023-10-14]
Centerpieces/Locking_spacer/1x12 Locking Spacer.stl
310.2 x 25.2 x 6.15

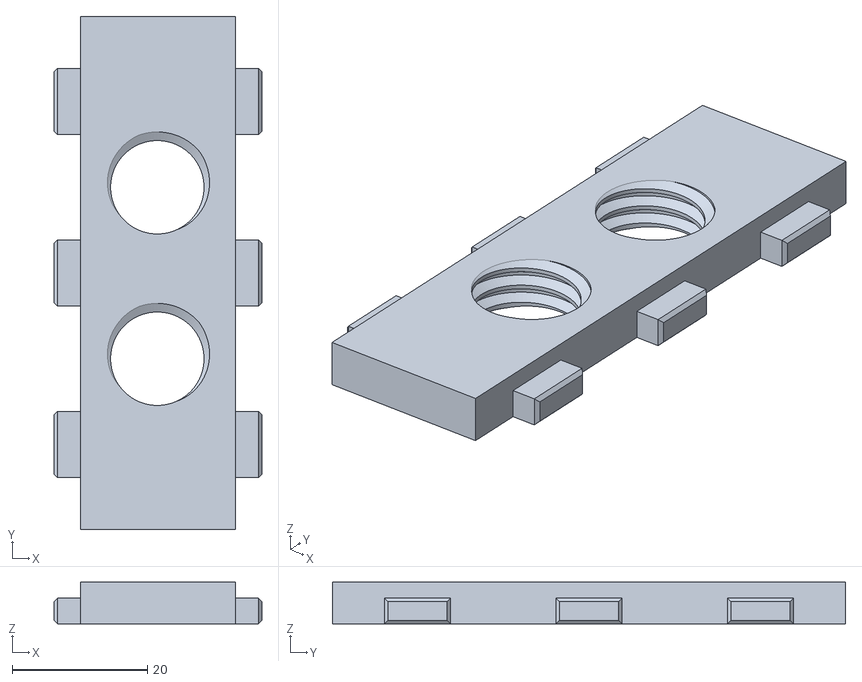
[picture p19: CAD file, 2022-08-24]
Centerpieces/Locking_spacer_for_horizontal_Wall_Control/3x1 Locking Spacer for horizontal Wall Control.stl
30.8 x 76.0 x 6.15

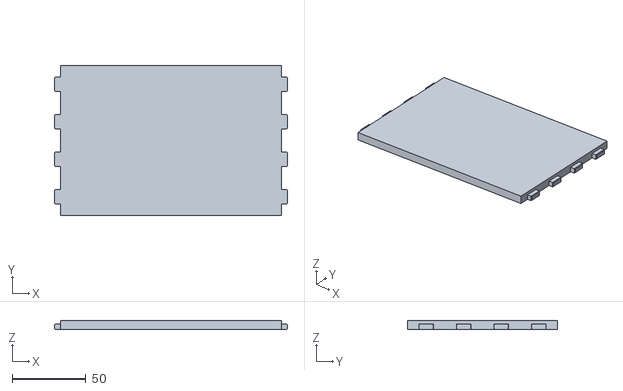
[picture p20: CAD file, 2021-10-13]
Centerpieces/Spacer_blank/4x6 Spacer blank.stl
157.8 x 101.4 x 6.15

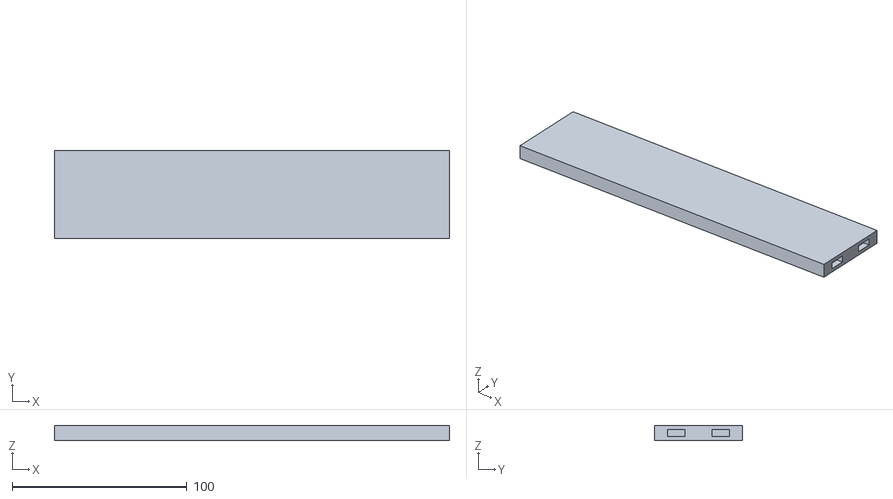
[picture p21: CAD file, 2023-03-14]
Centerpieces/Spacer_blank_flush/2x9 Spacer blank flush.stl
226.2 x 50.6 x 8.70

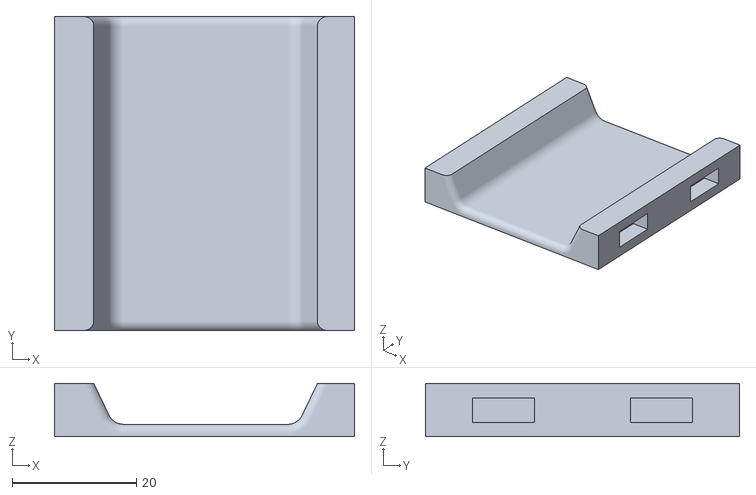
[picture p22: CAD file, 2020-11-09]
Centerpieces/Spacer_clip-on/2x2 Spacer clip-on.stl
48.4 x 50.6 x 8.60

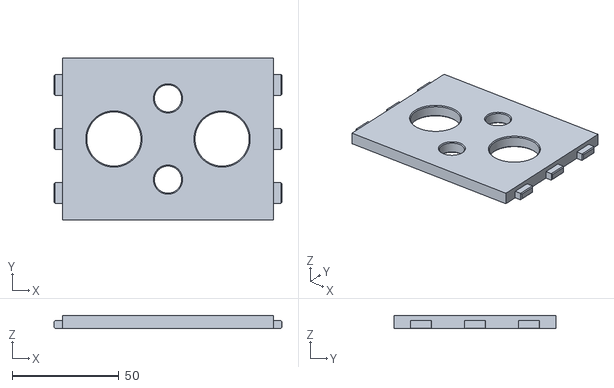
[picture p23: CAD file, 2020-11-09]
Centerpieces/Spacer_perforated/3x4 Spacer perforated.stl
107.0 x 76.0 x 6.15

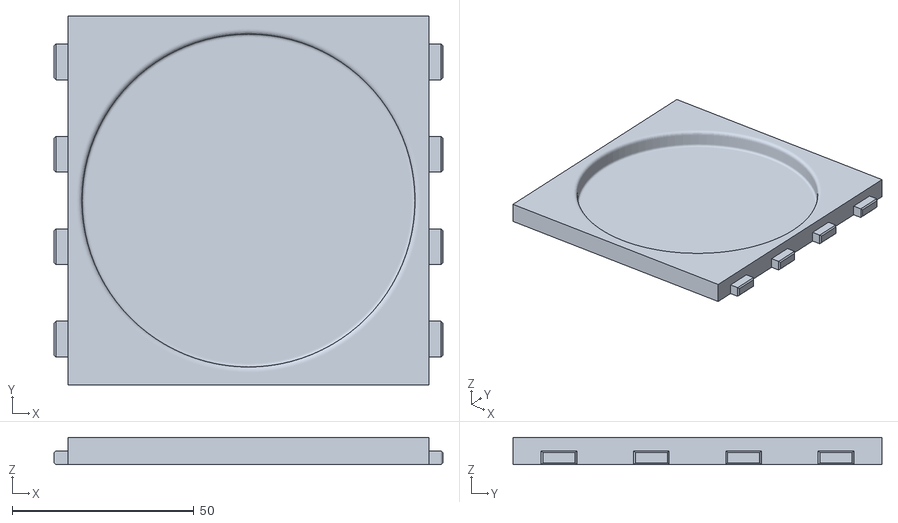
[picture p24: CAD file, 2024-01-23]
Centerpieces/Tool_hooks/4x4 Goldenrod 625 Pistol Pump Oiler.stl
107.0 x 101.4 x 7.50

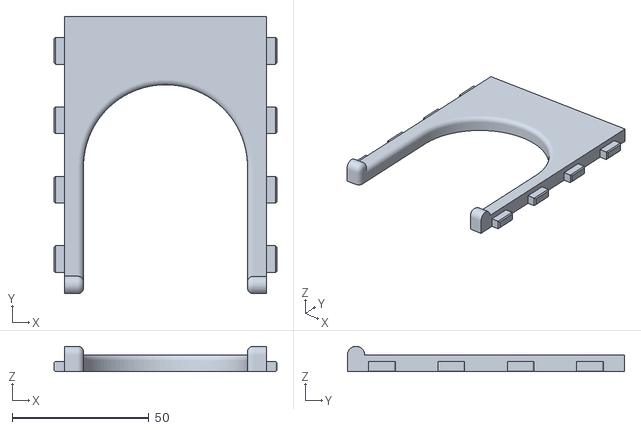
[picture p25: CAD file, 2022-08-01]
Centerpieces/U_hooks/4x3 60mm U hook catch.stl
81.6 x 101.4 x 9.32

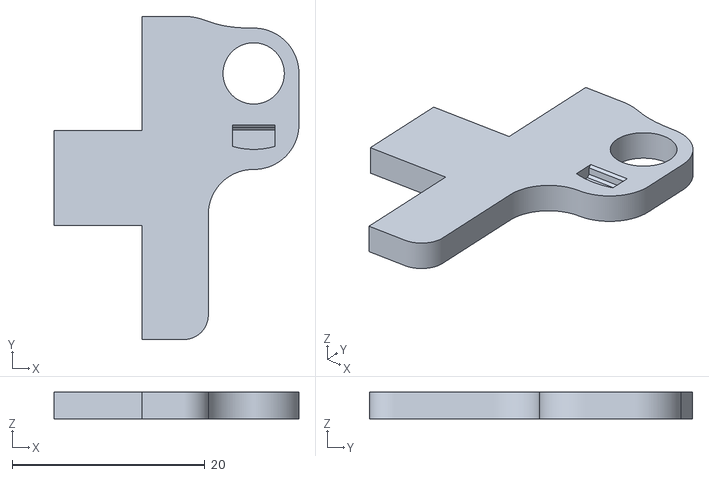
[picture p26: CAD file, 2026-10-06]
Quickhooks/Quickhook Lockable Retainer for Horizontal Wall Control.stl
25.4 x 33.5 x 2.79

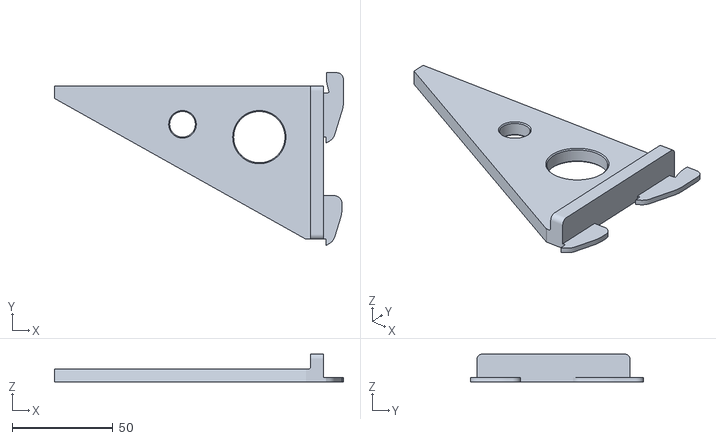
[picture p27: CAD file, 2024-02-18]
Sidepieces/Angle_brackets/3x5 Angle Bracket Flat Right.stl
143.4 x 85.7 x 13.7

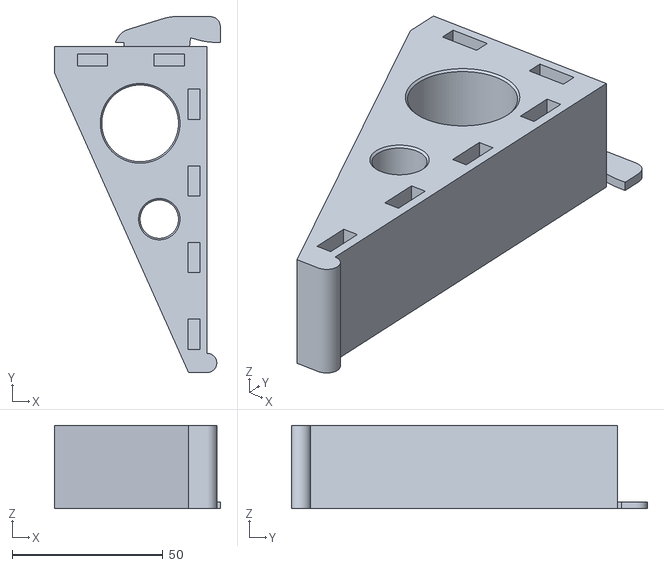
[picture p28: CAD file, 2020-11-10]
Sidepieces/Angle_brackets1/2x4 Angle Bracket Center.stl
55.0 x 118.0 x 27.6

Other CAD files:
Sidepieces/Dowel_rod_hanger/2x2 3-4in Dowel Rod Hanger Left.stl
Sidepieces/Flats/1x0 Flat Right.stl
Sidepieces/L_brackets/2x2 L Bracket Flat 2 Tier Right.stl
Sidepieces/Retainers/3x1 Locking Retainer for Horizontal Wall Control.stl
Accessories/3-4in Dowel Cap with Countersunk #8 Screw.stl
Accessories/3-4in Dowel Cap with Countersunk Screw.stl
Accessories/3-4in Dowel Cap.stl
Accessories/4x10x8mm Pin.stl
Accessories/8mm Lock Pin.stl
Accessories/Locking Screw thread model.stl
Accessories/Quickhook Retainer.stl
Accessories/Wall Control Mounting Screw Hole Plug.stl
Centerpieces/Gridfinity/2x10 Gridfinity Frame 1x6.stl
Centerpieces/Gridfinity/2x14 Gridfinity Frame 1x8.stl
Centerpieces/Gridfinity/2x2 Gridfinity Frame 1x1.stl
Centerpieces/Gridfinity/2x4 Gridfinity Frame 1x2.stl
Centerpieces/Gridfinity/2x6 Gridfinity Frame 1x3.stl
Centerpieces/Gridfinity/4x2 Gridfinity Frame 2x1.stl
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

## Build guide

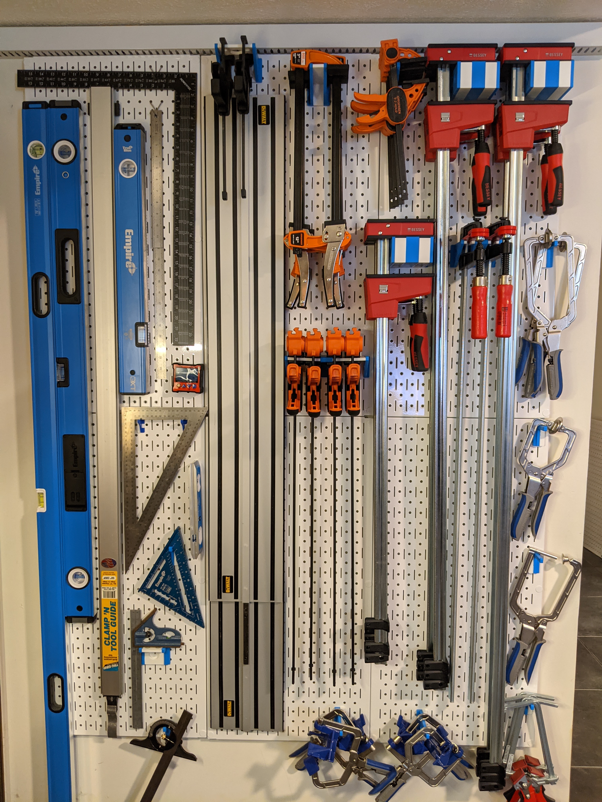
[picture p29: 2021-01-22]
images/DDD_Printable_Wall_Control_installed_03.jpg

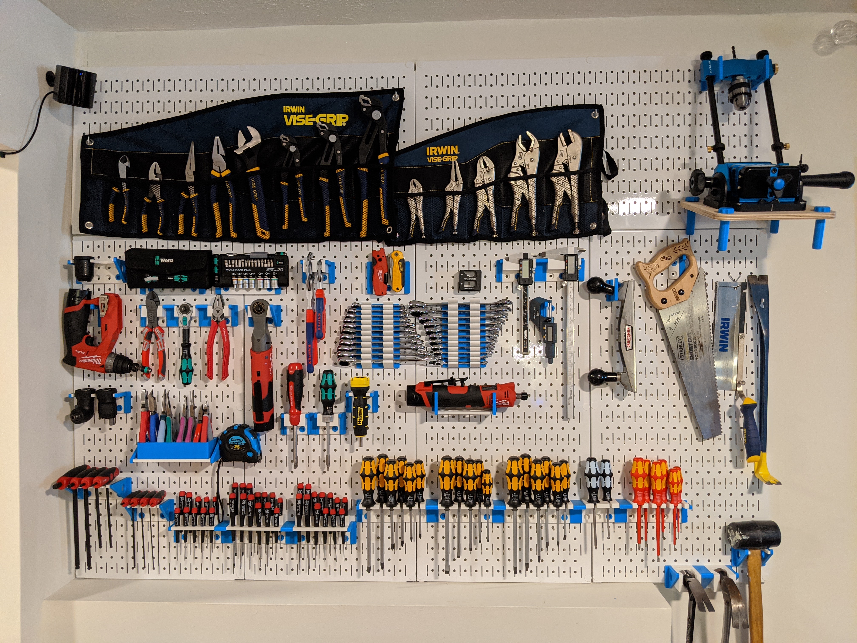
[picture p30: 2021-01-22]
images/DDD_Printable_Wall_Control_installed_01.jpg

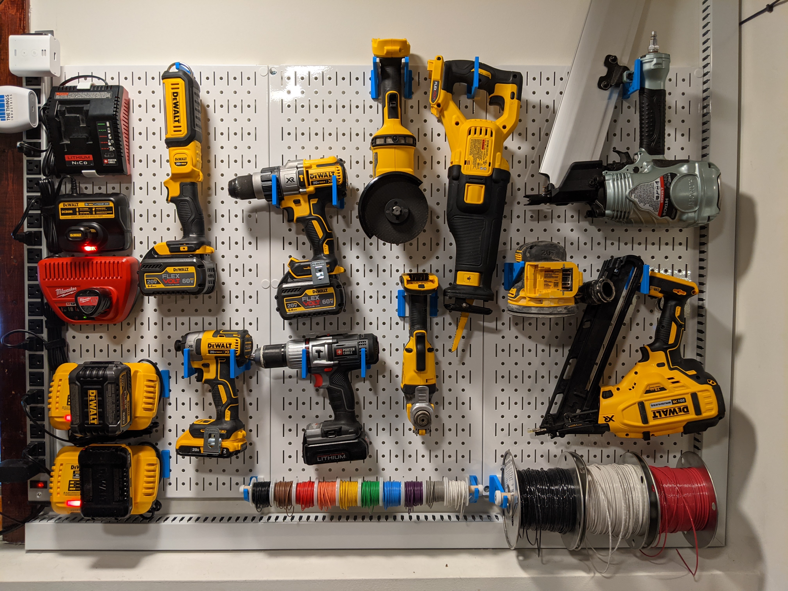
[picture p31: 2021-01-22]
images/DDD_Printable_Wall_Control_installed_02.jpg

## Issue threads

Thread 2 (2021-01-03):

Chinese Digital Calipers 150mm mounting documentation error

rkaronde, 2021-01-03:
The current instructions are
Designed for 150mm and 300mm calipers of the sort you'll find from various Chinese vendors. Combine with 2x2 L brackets and a 2x2 spacer.

- Should the spacer be 2x3?
- Should the bracket be 2x1?

Also both the tool holder and the bracket have a slot, how will the tool holder snap in the bracket?

aderusha, 2021-01-04:
Good catch and thanks for bringing it to my attention! I've updated the documentation on that part to better reflect reality 😃

One primary goal with my designs is to provide models that can be loaded directly into your slicer and print in the provided orientation without supports.  This can sometimes be challenging due to the geometry required by some models, and the calipers happen to be one of them.

Instead of printing the tabs on that model, as you've noted you'll find a slot.  What you'll need to do is to print 4x of the [4x10x8mm Pin](https://github.com/aderusha/DDD-Printable-Wall-Control-System/blob/main/Centerpieces/Spacer_blank_flush/4x10x8mm%20Pin.stl) models and press them into the slots to complete the assembled unit.

Closed 2021-01-04.

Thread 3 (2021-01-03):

CAD/SCAD source?

manutenfruits, 2021-01-03:
Thanks for this library! Would it be possible for you to share the CAD files you might have used to create the tools? I want to create my own centerpieces but have to recreate everything.

aderusha, 2021-01-04:
That's a reasonable request but it requires a shameful admission: I've been using SketchUp for ~15 years at this point and while it's poorly suited for 3D printing... It's what I know how to use.

So good news: YES I CAN provide the CAD files for everything.  Bad news: it's all being done in SketchUp (lol).  Further complicating things is that I'm working in SU2021, which has changed the document format such that tools like F360 can no longer import them.

manutenfruits, 2021-01-04:
That's fine, you built an awesome library! I'll gladly take SketchUp files and learn the basics, I just want to tweak some tool holders and take measurements to recreate on SolidWorks.

Thanks!

rkaronde, 2021-01-04:
I created a few tool holders in Fusion 360 after measuring the STL for the dimensions of other tool holder and where the slots/notches should be, and they fit great with the existing hooks.

Having said that if you can export and share STEP files that would be awesome..

aderusha, 2021-01-04:
Annoyingly, STEP export isn't offered by SketchUp without expensive 3rd-party add-ons.  STL is the most-portable solution I have available to me at the moment.

Someday I'll stop being dumb and learn F360...

Anyway I don't think I made it clear in my initial reply, the SU2021 source files can be found in the repo here: https://github.com/aderusha/DDD-Printable-Wall-Control-System/tree/main/SketchUp%20Sources

aderusha, 2021-01-04:
Oh and one more thing that might be surprising if you open this project up in SU2021 - everything is 1000x bigger than it is IRL.

Among the many reasons nobody should use SU for 3D printing is the extremely poor handling of small dimensions.  The solution I use is to model everything at 1000:1 scale, which is pretty easy as 1mm becomes 1m.  When you export to STL, select "meters" as the unit and everything should work out OK.

manutenfruits, 2021-01-04:
Thanks for the quick response and the files.

Closed 2021-01-04.

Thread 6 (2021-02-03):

Model error on Dowel Rod Holder

bgautrea, 2021-02-03:
The 2x4 3-4in Dowel Rod Hangers show a problem on the hook in Ultimaker Cura and ultimately dont print the hook. Not sure if this can be fixed in the slicer or if there's something up with the model. I may be doing something wrong here but the U-Brackets printed with no problem.

https://github.com/aderusha/DDD-Printable-Wall-Control-System/blob/main/Sidepieces/Dowel_rod_hanger/2x4%203-4in%20Dowel%20Rod%20Hanger%20Right.stl

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

aderusha, 2021-02-04:
It looks like Cura has some problem with the small radius on that part.  Maybe try PrusaSlicer? https://i.imgur.com/2Px77hI.png

The part is for sure manifold, so the issue here is the slicer.

bgautrea, 2021-02-04:
Thanks!. PrusaSlicer is working though I think it's still odd that some of the models work in Cura while others have the manifold issue. I assume the radius is == in all the models where the hook meets the rest of the model.

Closed 2021-02-04.

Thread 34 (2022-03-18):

2x4 Angle Bracket Inverted Flat Center missing?

RomanGz, 2022-03-18:
2x3 inverted center is there, but 2x4 is missing.

aderusha, 2022-08-01:
Resolved!

Closed 2022-08-01.

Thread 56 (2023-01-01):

My newly purchased 5,5mm Flat Driver no longer fits in this: Centerpieces/Tool_hooks/2x5 Wera Kraftform Plus 160i-6.stl

snebes, 2023-01-01:
This was a set purchased in 2022 from Amazon US. Specifically, this set:

https://products.wera.de/en/tools_for_electricians_kraftform_plus__series_100_vde_160_i_6_rack.html

The 5.5mm flat driver no longer fits in the supplied location on this STL: Centerpieces/Tool_hooks/2x5 Wera Kraftform Plus 160i-6.stl

All other drivers fit exactly as expected.

I'm not able to find any dimensional specifications for that specific driver, but I measured this with my caliper:

shaft near top: 8.9mm
handle base (hexagon edge-to-edge): 23.0mm (a hair under)

aderusha, 2024-07-16:
Looking to either close or resolve this issue - the model as provided fits the measurements you indicate, which also match the driver.

Here's a look at that model, the hex cutout is 23.4mm dia and the shaft cutout is 9mm dia: https://i.imgur.com/4UqmA5k.png

On the off chance that you're still watching this, go ahead and respond if this is still an issue and I'll re-open.  Sorry for the late response!

Closed 2024-07-16.

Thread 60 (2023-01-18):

Unable to download any angle bracket sidepieces.

MrJSaul, 2023-01-18:
Unable to download any angle bracket sidepieces.  There is no button for downloading on any of the pages in this section it seems.  Am I missing something?  All the other items have had a "Download" button and had no issue.

rgeyer, 2023-01-23:
You should also be able to click on the `Raw` button which will open it up in your browser. Then use the file menu or right click on the page and "Save As.." to save the file.

ffcruz85, 2023-02-22:
what @rgeyer said, or just clone the whole repository locally. If you don't want to mess with git or installing github desktop, you can just go to the main page of the repo, click the green code button, and then click download ZIP to get the whole repo downloaded. If you clone it, however, you can more easily get updates to it.
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

MrJSaul, 2023-02-22:
Thanks @rgeyer @ffcruz85.  I really appreciate you both taking the time to point this noob in the right direction and educating me on what is possible.

ffcruz85, 2023-02-22:
No problem. Even if you're not familiar with git, you could try the GitHub desktop app, it's fairly user friendly and then you can "sync" (pull commits to local clone of the repository) and have the new stuff that gets added here. Maybe even contribute your own designs 😉

MrJSaul, 2023-02-22:
@ffcruz85
I did remix 2 items for this system.  How can I add them?
1) Open top small mason jar holder (remix: https://www.thingiverse.com/thing:2552603)
2) Benzomatic propane bottle/torch holder (remix https://www.thingiverse.com/thing:3332178)

ffcruz85, 2023-02-22:
So, you have to do it on your own copy of the repository, and then ask to merge it back into this main one. You don't need to install the app and call do it all on the website.

1. First, you need to fork the repo, which is getting your own copy of the repo that you then own and can edit. Just go to the main page and click fork on the buttons at the top. Then you will have your own copy at https://github.com/MrJSaul/DDD-Printable-Wall-Control-System
2. Then add the files for those things you made under the centerpieces/tool_hooks folder
3. Preferably, name your files according to the pattern used, which is explained in the README.md file in that tool_hooks folder, e.g.: 2x4_Propane_Torch_Holder.stl
4. You should also edit the README.md file to add your tools to the list so people can find them, it's formatted in markdown, which is a syntax for making text formatting in plain text, making the links to the files, etc. Easiest way: just copy one of the existing tool holder descriptions and change the name, description, and link to the file.
5. Now that you are done adding your files and describing them in the readme in your own repo, just come back here to @aderusha 's main repo, and click on pull requests, create new pull request, and it should already have your fork in the options of where you are pulling from. Just write a quick note saying what you are adding, click submit, and that's it. @aderusha will see it, and if it's all good, he'll merge and then you tools will be available here for the community!

You can just go to pull requests page right now, and click on closed to see those that have already been merged - you will see one i recently added to do exactly what you did, and it will show the changes I made, which you can use as an example

ffcruz85, 2023-02-22:
@MrJSaul also, if you are no longer having the original problem for which you opened this issue, you can go ahead and close it. That concludes this very short course on contributing in github :)

ffcruz85, 2023-02-22:
@MrJSaul PS.: If you have any CAD type files or a STEP file for your designs, it might also be nice to include those so people can make further remixes!

Closed 2023-02-22.

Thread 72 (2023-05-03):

\Sidepieces\Angle_brackets\3x5 Angle Bracket Flat Right.stl

roto-c17, 2023-05-03:
can you please verify that "\Sidepieces\Angle_brackets\3x5 Angle Bracket Flat Right.stl" is correct, it is as thick as the "\3x5 Angle Bracket Flat Center.stl"  (27.6mm), when I expected it to be the same thickness as the "\3x5 Angle Bracket Flat Left.stl" (13.7mm).  Thank you for your time, and your amazing work on this collection.

roto-c17, 2023-07-01:
> I can confirm, "3x5 Angle Bracket Flat Right" looks like a copy of "3x5 Angle Bracket Flat Center". The files are very nearly identical. I _think_ one can just mirror the left one to get a right one, unless I'm missing something...

Thank you, i did mirror Left to get the right one, and it worked great.  Recommend removing the "3x5 Angle Bracket Flat Right.stl" file so someone doesn't inadvertently print a center piece.  Thanks agin.

Closed 2023-07-01.

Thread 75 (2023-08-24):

Missing File - Centerpieces/Tool_hooks/2x3%206x%206mm%20Finger%20Slots.stl

Kneifel, 2023-08-24:
I get a 500 error message when trying to download

An unexpected 500 error occured

And then a complete failure when I reload

[Centerpieces/Tool_hooks/2x3%206x%206mm%20Finger%20Slots.stl](https://github.com/aderusha/DDD-Printable-Wall-Control-System/blob/main/Centerpieces/Tool_hooks/2x3%206x%206mm%20Finger%20Slots.stl)

Closed 2023-08-24.

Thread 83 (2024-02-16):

3x5 Angle bracket flat right and 3x5 angle bracket flat center are the same file.......i think?

aBlindReefer, 2024-02-16:
I'm severely visually impaired so forgive me if I'm wrong, which I probably am. I'm making some organizers for my wall control pegboard and was printing some gridfinity shelfs using the 3x5 angle flat brackets (left, center, right), My prints for the right bracket are the same as the center bracket. Can you fix the 3x5 angle bracket flat right file, or just tell me that I am crazy? Thank you! I'm pretty new to printing and vision loss so forgive me if I'm wrong.

aderusha, 2024-07-16:
Fixed, and thanks!

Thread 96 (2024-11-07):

Fusion 360 Source File Duplicate?

Rwings39, 2024-11-07:
If I'm not mistaken, it looks like the "Vertical Locking Spacers Part 2.fd3" and "Vertical Locking Spacers Part 3.fd3" files are identical?  Even the file sizes matched when I downloaded them.  I'm not sure if this is a duplicate from saving version histories in Fusion and there should only be two sets, or if there is a set of Locking Spacers that's missing.

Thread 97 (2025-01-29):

AA Battery Holders don't match up with pattern

SuperRonanCraft, 2025-01-29:
I was trying to add a 2x1 locking spacer and also use these as a normal battery holder but the distance between the battery towers are not enough to let a AA battery between, and the space between don't match up with the spacers at all. Any way to possibly fix this?

Heres some images of the problem
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

SuperRonanCraft, 2025-01-30:
never mind, found out what I gotta do

Closed 2025-01-30.

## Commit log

2020-11-09 Centerpiece Spacer Collection vol 001
    [1x1 Spacer blank.stl, 1x2 Spacer Perforated.stl, 1x3 Spacer Perforated.stl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]
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2020-11-10 Add Wiha T-Handle set, change case on Angle brackets
    [2x2 Angle Bracket Center.stl, 2x2 Angle Bracket Left.stl, 2x2 Angle Bracket Right.stl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]
2020-11-10 Case conversion on Angle brackets
    [2x2 Angle Bracket Center.stl, 2x2 Angle Bracket Left.stl, 2x2 Angle Bracket Right.stl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]
2020-11-10 Add Vampliers and NWS Fantastico
    [NWS 138-69-200 Fantastico Plus Side Cutters.stl, Vampliers VT-001-8.stl, Wera 3-8 Zyklop Ratchet.stl]
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2020-11-19 Add L Bracket Flat + 10x screwdrivers
    [2x1 L Bracket Flat Center.stl, 2x1 L Bracket Flat Left.stl, 2x1 L Bracket Flat Right.stl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]
2020-11-19 Add dowel rod hangers
    [2x3 3-4in Dowel Rod Hanger Left+Right.3mf, 2x3 3-4in Dowel Rod Hanger Left.stl, 2x3 3-4in Dowel Rod Hanger Right.stl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]
2020-11-19 Fix gitignore
    [2x3 3-4in Dowel Rod Hanger Left+Right.3mf]
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2020-12-04 Add 3in and 5in flats
    [3x0 Flat Center.stl, 3x0 Flat Left.stl, 3x0 Flat Right.stl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]
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2020-12-07 Fix angle bracket catch alignment error
    [2x2 Angle Bracket Flat Center.stl, 2x2 Angle Bracket Flat Left.stl, 2x2 Angle Bracket Flat Right.stl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]
2020-12-31 Add screw hole plug to project
    [Wall Control Mounting Screw Hole Plug.stl]
2021-01-04 Add source files, fix some documentation
    [DDD Printable Wall Control Quickhooks.skp]
2021-01-19 Add 2in U brackets
    [2x2.5 2in U Bracket Center.stl, 2x2.5 2in U Bracket Left.stl, 2x2.5 2in U Bracket Right.stl]
2021-01-19 Add details on locking screw spacer usage
    [4x10x8mm Pin.stl, 8mm Lock Pin.stl, Quickhook Retainer.stl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]
2021-01-19 Fix lock pin links
2021-01-22 Add dowel caps and installed images
    [3-4in Dowel Cap with Countersunk Screw.stl, 3-4in Dowel Cap.stl]
2021-02-03 Move angle brackets to correct folder
    [2x2 Angle Bracket Inverted Flat Left.stl, 2x2 Angle Bracket Inverted Flat Right.stl]
2021-04-22 Add R8 Taper tool holder
    [2x5 3x R8 Taper Tools.stl]
2021-06-11 Add Wera T-Handle driver models
    [2x4 Wera HexPlus T-Handle Imperial Small.stl, 2x5 Wera HexPlus T-Handle Imperial Large.stl, 2x6 Wera HexPlus T-Handle Metric.stl]
2021-06-13 Fix wall hook Z offset
    [2x2 Angle Bracket Hook Center.stl, 2x2 Angle Bracket Hook Left.stl, 2x2 Angle Bracket Hook Right.stl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]
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2021-07-26 Add 3x3.25 2.5in U Brackets
    [3x3.25 2.5in U Bracket Center.stl, 3x3.25 2.5in U Bracket Left.stl, 3x3.25 2.5in U Bracket Right.stl]
2021-07-26 Add DeWalt 20v+60v battery mount
    [3x3 DeWalt 20v+60v battery mount.stl]
2021-07-28 Add DeWalt battery mount without clip feature
    [3x3 DeWalt 20v+60v battery mount no-clip.stl]
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2021-10-16 Add locking screw thread model
    [Locking Screw thread model.stl]
2021-10-18 Update thread model to include 6.75mm dia valley
    [Locking Screw thread model.stl]
2021-11-18 Add locking models for horizontal Wall Control panels
    [2x1 Locking Retainer for Horizontal Wall Control.stl, 2x1 Locking Spacer for horizontal Wall Control.stl, 2x2 Locking Spacer for horizontal Wall Control.stl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]
2021-11-18 Add 15x screwdriver holder model
    [2x6 15x 10mm Screwdriver Holder.stl]
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2021-11-26 Add Wera Nutdrivers and pliers rack
    [2x3 Wera 395 HO 6-5.5-5.stl, 2x6 Wera 395 HO 7-8-10-13.stl, 3x4 Spacer blank flush.stl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]
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2022-01-04 Add files via upload
    2x4 Angle Brackets, inverted - needed for 4 tier screwdriver holder.
    [2x4 Angle Bracket Inverted Flat Left.stl, 2x4 Angle Bracket Inverted Flat Right.stl]
2022-01-04 Add files via upload
    Some new centerpieces I use.
    [2x5 Irwin Pliers Crimper Stripper.stl, 2x5 Irwin Pliers LgLock Linemans.stl, 2x5 Irwin Pliers LgNeedle AviationSnips.stl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]
2022-03-06 3x4 Slatwall Adapter
    Allows for the use of standard Slatwall accessories with DDD Printable Wall Control System
    Print with a left/right set of 4x0 Flats
    [3x4 Slatwall Adapter.stl]
2022-03-07 3x4 Slatwall Adapter Flush
    [3x4 Slatwall Adapter Flush.stl]
2022-07-22 Moved SketchUp files to Sources/SketchUp
    [DDD Printable Wall Control Quickhooks.skp]
2022-07-22 Added Quickhooks FreeCAD file
    [Quickhooks.FCStd]
2022-07-24 Added missing retainer. Added length params
    [Quickhooks.FCStd]
2022-07-24 Added Spacers FreeCAD file
    [Spacers.FCStd]
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2022-08-01 DDD Printable Wall Control Quickhooks
    [DDD Printable Wall Control Quickhooks.skp]
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2022-08-07 Fix 2x5 angle model
    [2x5 Angle Bracket Flat Center.stl]
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2022-08-26 Add centerpiece for holding Milwaukee M12 Installation Drill
    [3x2 Milwaukee M12 Installation Drill Lock.stl, 3x2 Milwaukee M12 Installation Drill.stl]
2022-08-30 Minor edit to the awesome M12 driver by @jamesalmeida
    [2x4 Milwaukee M12 Installation Drill 2x Driver Heads.stl, 3x2 Milwaukee M12 Installation Drill.stl, 4x2 Milwaukee M12 Installation Drill Lock.stl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]
2022-10-10 Add STL to hold a Riden RD6006P DC Power Supply
    [6x4 RD6006P_Power_Supply.stl]
2022-10-10 Fix up solid geometry and make printable without supports
    [6x4 RD6006P_Power_Supply.stl]
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2022-11-21 added new sizes of blank flush spacers for use in some custom tool holders
    [2x10 Spacer blank flush.stl, 2x8 Spacer blank flush.stl, 2x9 Spacer blank flush.stl]
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2023-01-01 Added a new Wera Kraftform Plus 160i-6 centerpiece that includes labels
    [2x7 Wera Kraftform Plus 160i-6 with labels.stl]
2023-01-06 M12 Milwaukee Battery and tool holders
    Holders to store 1, 2, or 3 Milwaukee M12 batteries, and generic M12 tool holders that can store any M12 system tool because they use the battery slot to hold the tool
    [2x1_Milwaukee_M12_tool_holder_angled.stl, 2x1_Milwaukee_M12_tool_holder_straight.stl, 2x1_Milwaukee_M12_tool_holder_straight_extended.stl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]
2023-03-14 Fix dowel cap to actually fit 3/8" dowel
    [2x2 L Bracket Hook Inverted Left.stl, 2x4 L Bracket Flat Center.stl, 2x4 L Bracket Flat Inverted Center.stl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]
2023-04-30 Added Milwaukee M12+M18 combo charger centerpiece
    As an alternative to the nubs on the M12 charger piece, I left holes for hot melt inserts for M4 machine screws. The nubs just popped straight off when I tried to hang it up. It should be easy enough to swap nubs for insert holes, though.
    [4x3 Milwaukee M12+M18 Combo Charger.stl]
2023-04-30 New tool holder
    Tool holder for the Park Tool THT-1 Sliding T-Handle Torx Compatible Wrench Set. Photos at https://www.printables.com/model/467102-park-tool-tht-1-sliding-t-handle-torx-compatible-w
    [5x2 Park Tools Torx Set.stl]
2023-07-03 Changed parameter for tab spacing from 26mm to 25.4mm (1 inch)
    [Parametric Centerpiece Template.f3d]
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2024-02-18 Fix 3x5 Angle Bracket Flat Right
    [3x5 Angle Bracket Flat Right.stl]
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2024-03-20 Re-wrote FeeCad source to match STL measurements.
    Re-named parameters and updated descriptions to be more clear.
    [Spacers.FCStd]
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2024-07-16 Flip honeycomb front-to-back
    [4x4 Honeycomb Storage Wall.stl, 6x6 Honeycomb Storage Wall.stl, 6x8 Honeycomb Storage Wall.stl]
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
